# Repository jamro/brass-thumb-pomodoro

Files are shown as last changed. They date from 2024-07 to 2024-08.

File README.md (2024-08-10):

# Brass Thumb Pomodoro

The Brass Thumb Pomodoro is a unique productivity timer inspired by the [Pomodoro Technique](https://en.wikipedia.org/wiki/Pomodoro_Technique) and designed in a delightful steampunk style. This timer, powered by the [Arduino](https://www.arduino.cc/) platform, helps you manage work and rest periods effectively. With 25-minute work intervals followed by 5-minute breaks, the device features a side switch to set the mode. Upon completing a work session, a thumbs-up figure pops out as a reward. The entire gadget is USB-powered and designed with 3D-printed parts, making it portable and convenient to use.

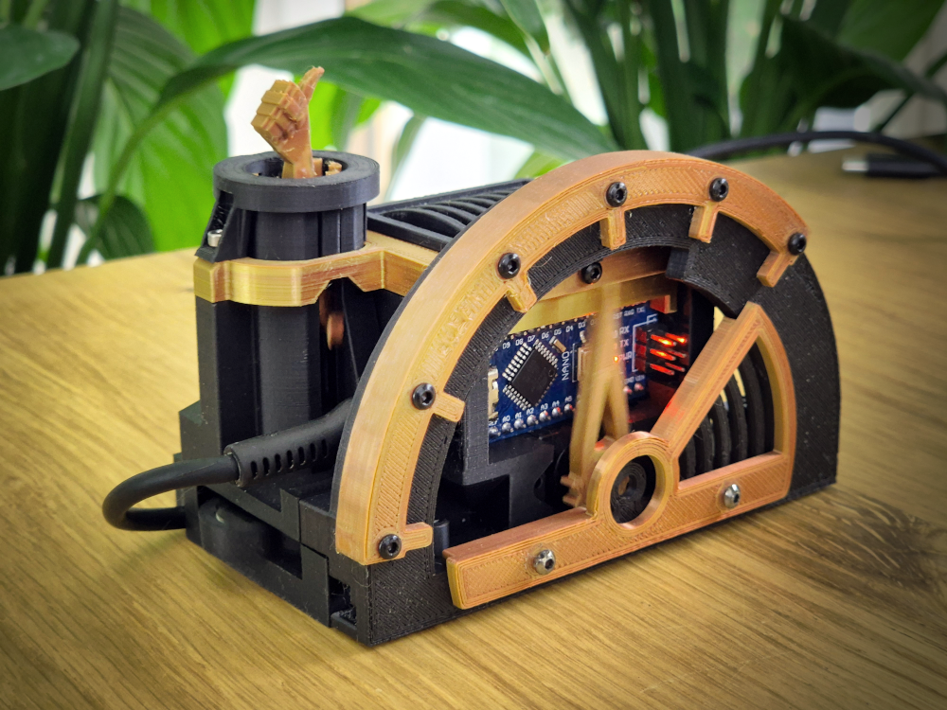
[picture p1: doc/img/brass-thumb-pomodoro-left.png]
Brass Thumb Pomodoro Left View

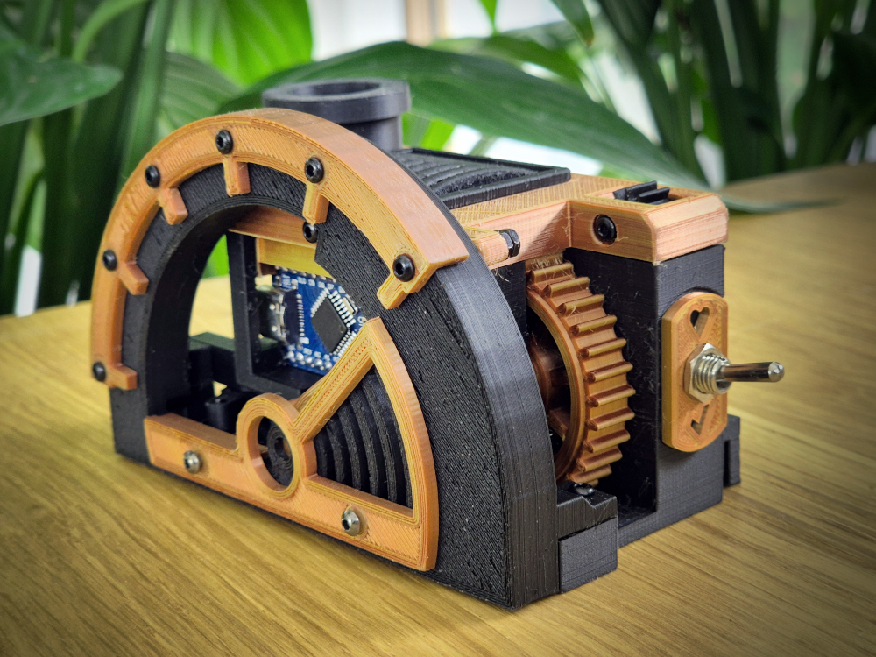
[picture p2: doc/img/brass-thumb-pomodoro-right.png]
Brass Thumb Pomodoro Right View

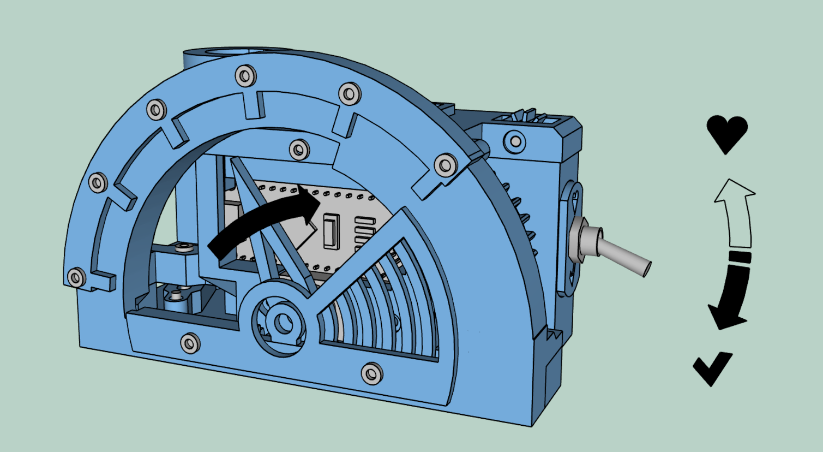
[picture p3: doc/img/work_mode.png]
Work mode


## Documentation

1. **[Materials List](doc/materials_list.md)**
2. **[3D Printing](doc/3d_printing.md)**
3. **[Upload Code](doc/upload_code.md)**
4. **[Wiring Electronics](doc/wiring_electronics.md)**
5. **[Device Assembly](doc/device_assembly.md)**
6. **[User Manual](doc/user_manual.md)**

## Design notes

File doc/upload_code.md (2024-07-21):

# Upload Code

Follow these detailed instructions to build and upload the Brass Thumb Pomodoro project to your Arduino Nano.

## Step 1: Locate the Arduino Sketch Folder

The Arduino IDE stores sketches (projects) in a predefined location known as the "Sketchbook" folder. To find out where this folder is located on your system:

1. Open the Arduino IDE.
2. Go to `File` -> `Preferences`.
3. In the `Preferences` window, locate the `Sketchbook location:` field. This shows the directory where your sketches are stored.

## Step 2: Create the Project Directory

1. Navigate to the Sketchbook location using your file explorer or terminal.
2. Inside the Sketchbook folder, create a new subfolder named `brass-thumb-pomodoro`.

## Step 3: Move Source Files

1. Copy all contents from the `/src` folder of the Brass Thumb Pomodoro project (e.g., `brass-thumb-pomodoro.ino`, `config.h`, `lib/Clock.h`, `lib/Clock.cpp`, and any other necessary files).
2. Paste these files into the `brass-thumb-pomodoro` folder you just created in your Sketchbook directory.

Your folder structure should look like this:
```
Arduino/Sketchbook/
    └── brass-thumb-pomodoro/
        ├── brass-thumb-pomodoro.ino
        ├── config.h
        └── lib/
            ├── Clock.h
            ├── Clock.cpp
            └── ... (other library files)
```

## Step 4: Open the Project in Arduino IDE

1. In the Arduino IDE, go to `File` -> `Sketchbook`.
2. You should see a list of folders within your Sketchbook directory. Click on `brass-thumb-pomodoro`.

This will open the `brass-thumb-pomodoro.ino` file in the Arduino IDE.

## Step 5: Select Arduino Nano

1. Connect your Arduino Nano to your computer via USB.
2. In the Arduino IDE, go to `Tools` -> `Board` and select `Arduino Nano`.
3. Still under `Tools`, select the appropriate processor. Usually, this is `ATmega328P (Old Bootloader)` or `ATmega328P`, depending on your specific Nano version.
4. Under `Tools` -> `Port`, select the port to which the Arduino Nano is connected (e.g., `COM3` on Windows or `/dev/ttyUSB0` on Linux).

## Step 6: Build and Upload

1. To ensure that all components are compiled correctly, click the checkmark (✓) button in the upper-left corner of the Arduino IDE. This runs a verify/compile check.
   - If there are any errors, review the messages in the console for guidance on fixing them.
2. Once the code compiles without errors, click the right-arrow (→) button (Upload) to upload the code to the Arduino Nano.

## Troubleshooting

- **Compilation Errors**: Ensure that all necessary files are within the `brass-thumb-pomodoro` folder. Missing files can cause compilation issues.
- **Port Issues**: Verify that the correct port is selected under `Tools` -> `Port`. You may need to disconnect and reconnect the USB cable or restart the Arduino IDE to resolve port detection issues.
- **Board Not Detected**: Make sure drivers for the Arduino Nano are correctly installed. Some unofficial Nanos require the installation of additional CH340 drivers.
- **Mode Switch Orientation**: If the mode switch is installed upside down, the positions of the WORK and BREAK modes will be inverted. To fix this:
    1. Open the `config.h` file in the `brass-thumb-pomodoro` folder.
    2. Swap the following values:
        ```cpp
        constexpr int WORK_PIN = 2; // was 3
        constexpr int BREAK_PIN = 3; // was 2
        ```
    3. Save the file and re-upload the code to the Arduino Nano.

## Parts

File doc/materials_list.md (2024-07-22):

# List of Materials

## Electronics
- [Arduino Nano (clone with USB-C)](https://sklep.msalamon.pl/produkt/nano-v3-0-z-usb-c-zgodny-z-arduino)
- [3 Position Switch](https://sklep.msalamon.pl/produkt/przelacznik-dzwigniowy-pojedynczy-spdt-3p/)
- Servo Redox S90
- Female Jumper Wires

## Screws
- 11 x M2x8 Screws
- 5 x M2x16 Screws

## Filaments
- [PLA Matte Black (65g)](https://eryone3d.com/products/matte-pla)
- [PLA Copper (25g)](https://sklep.rosa3d.pl/product/pla-silk-175mm-copper-08kg/)

## Tools
- 3D Printer
- Soldering Iron
- Tin
- Mini Screwdriver

## Preparation
Ensure you collect all necessary parts before starting the assembly.

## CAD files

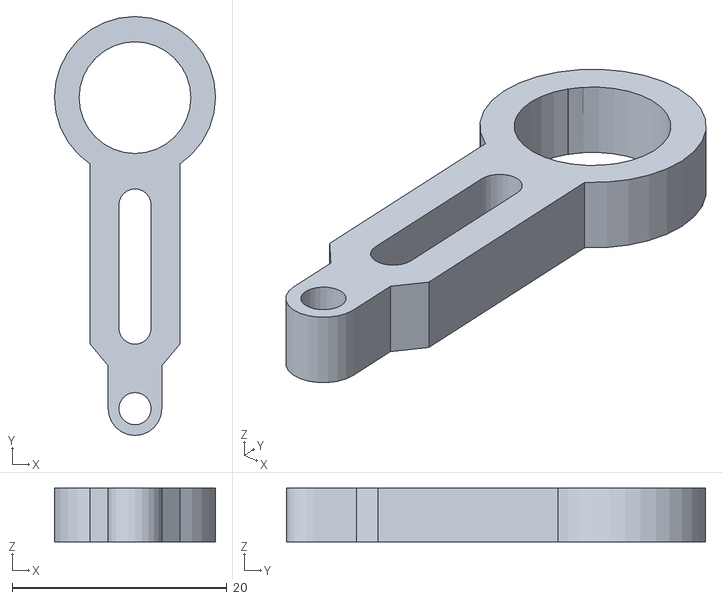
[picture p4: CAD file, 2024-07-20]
model/stl/gauge_handle.stl
15.0 x 39.0 x 5.00

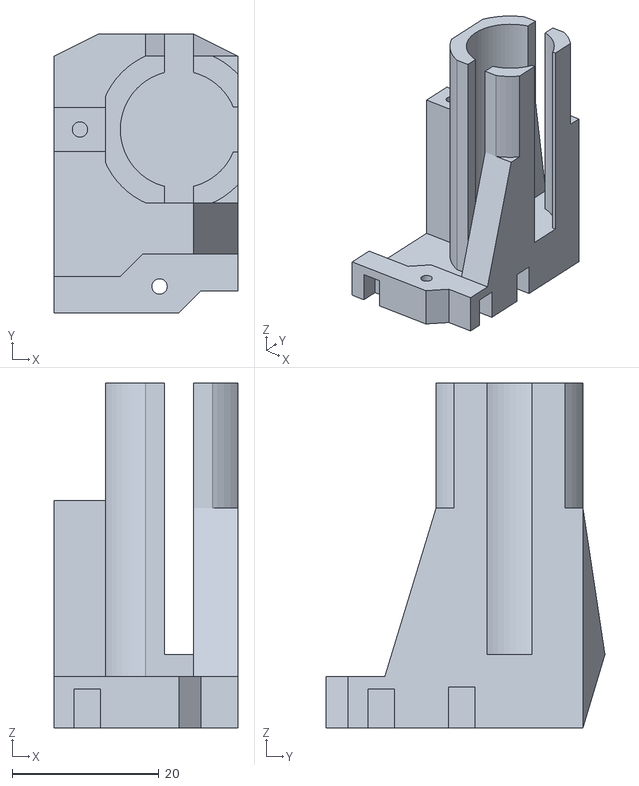
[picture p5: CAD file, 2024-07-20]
model/stl/gauge_tower.stl
25.0 x 38.0 x 47.0

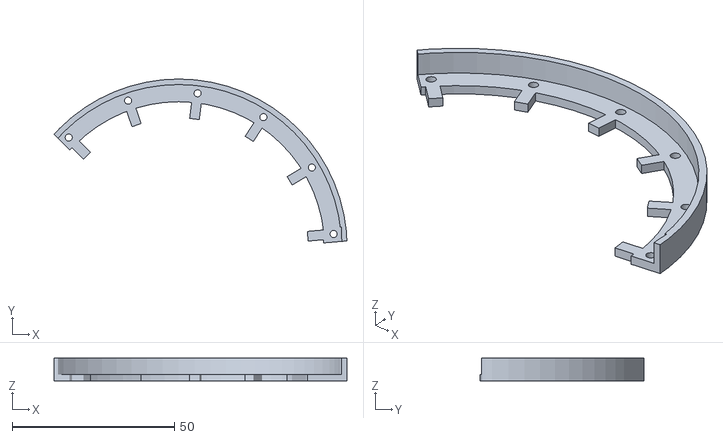
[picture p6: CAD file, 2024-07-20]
model/stl/gauge_scale_ticks.stl
90.4 x 50.6 x 7.00

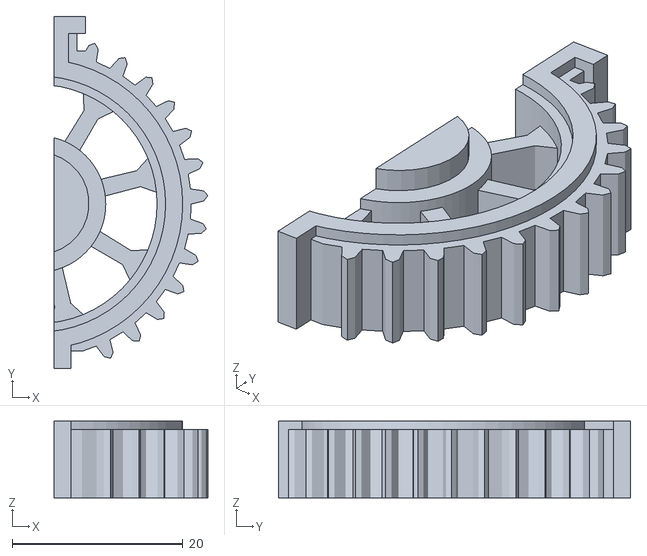
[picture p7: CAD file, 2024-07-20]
model/stl/gauge_gear_large.stl
18.0 x 41.2 x 9.00

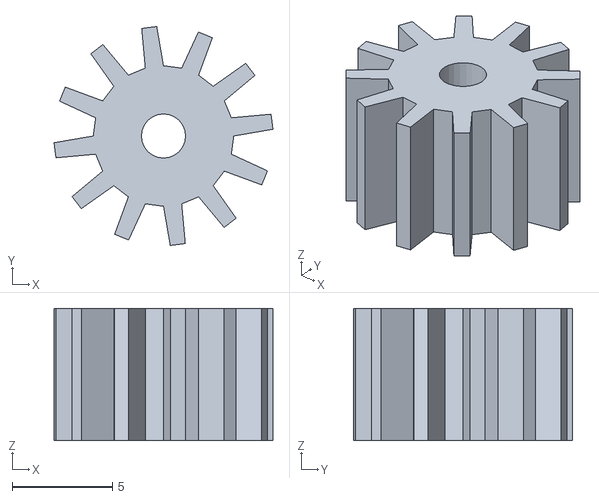
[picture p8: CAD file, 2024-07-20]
model/stl/gauge_gear_small.stl
10.9 x 10.9 x 6.60

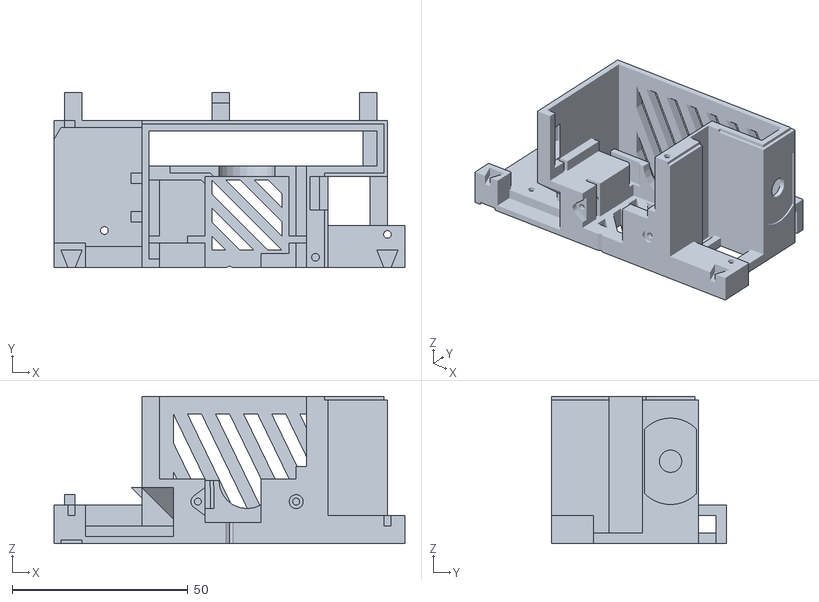
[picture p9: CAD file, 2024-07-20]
model/stl/gauge_case.stl
100.0 x 50.0 x 42.0

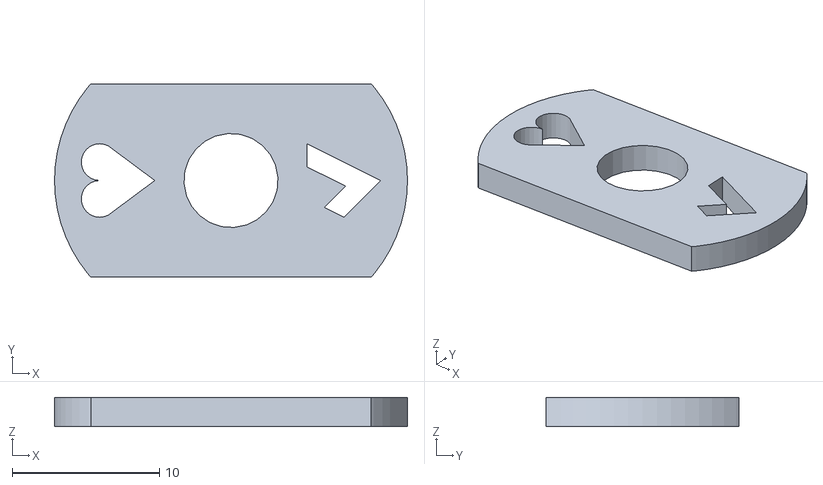
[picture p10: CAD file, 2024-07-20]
model/stl/gauge_tag.stl
24.0 x 13.1 x 2.00

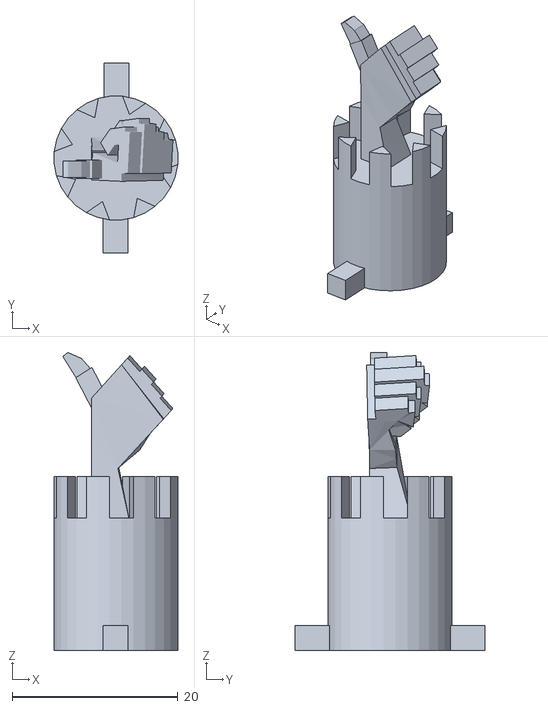
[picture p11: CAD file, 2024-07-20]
model/stl/gauge_popup.stl
14.9 x 22.9 x 36.0

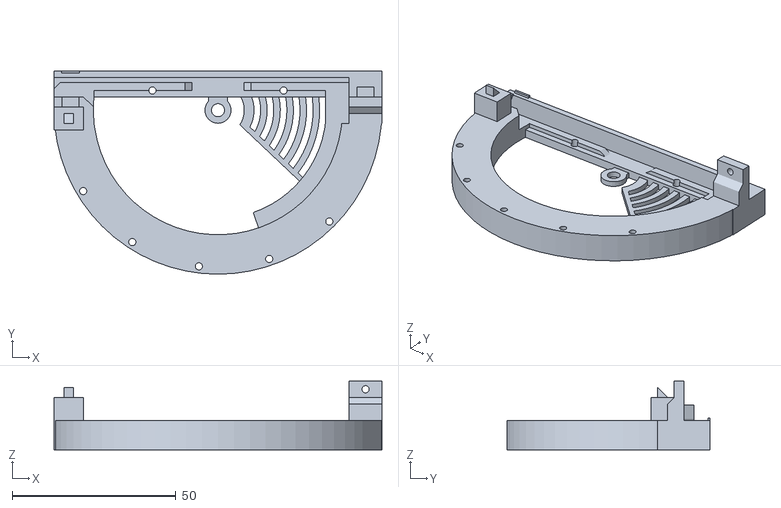
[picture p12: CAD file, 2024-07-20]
model/stl/gauge_scale_body.stl
100.0 x 62.0 x 21.0

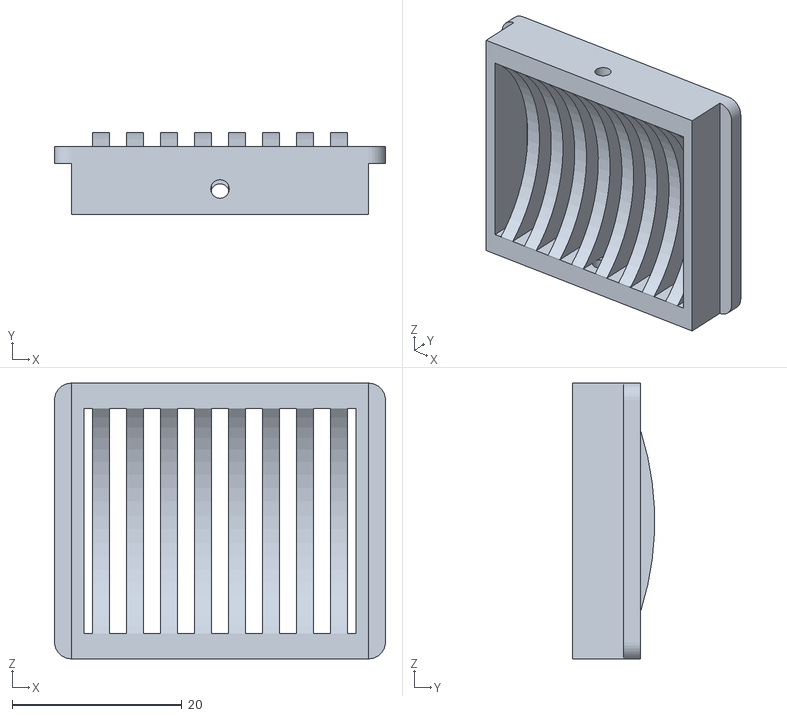
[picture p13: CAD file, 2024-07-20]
model/stl/gauge_vent.stl
39.0 x 9.65 x 32.5

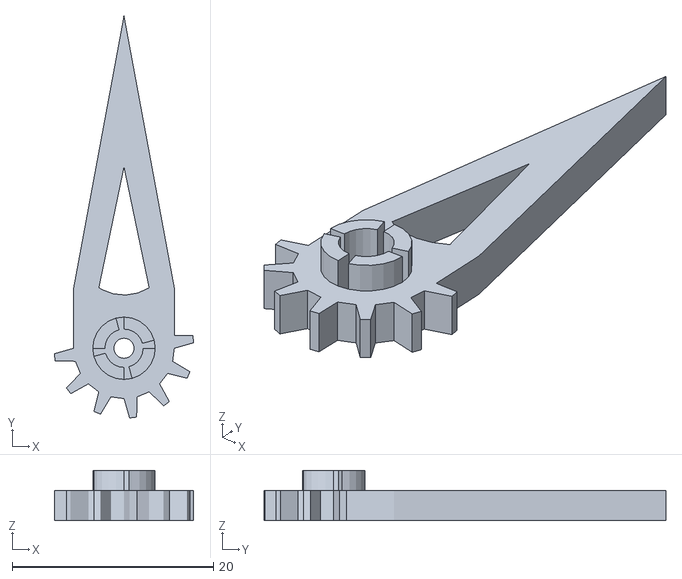
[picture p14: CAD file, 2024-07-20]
model/stl/gauge_pointer.stl
13.9 x 39.9 x 5.00

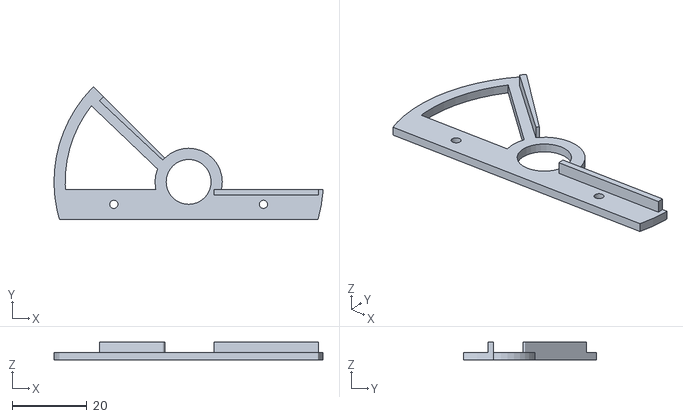
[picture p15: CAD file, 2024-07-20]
model/stl/gauge_scale_front.stl
71.9 x 35.4 x 4.70

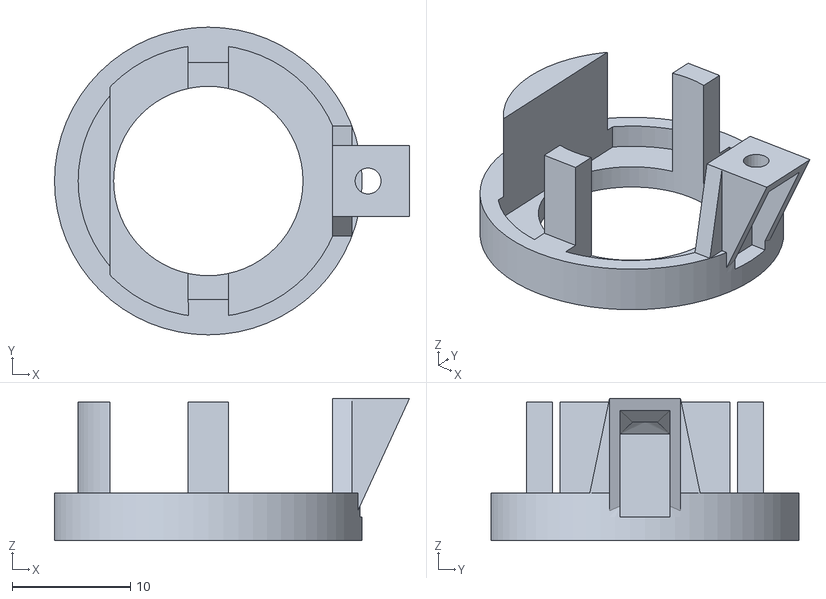
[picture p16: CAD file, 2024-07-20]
model/stl/gauge_tower_top.stl
30.0 x 26.0 x 12.0

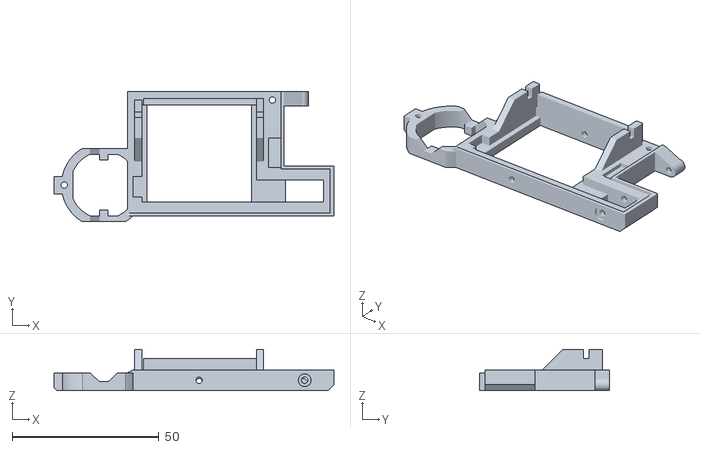
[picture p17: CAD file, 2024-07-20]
model/stl/gauge_cap.stl
95.5 x 44.5 x 14.0

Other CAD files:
model/stl/gauge_slider.stl
model/skp/gauge_cap.skp
model/skp/gauge_case.skp
model/skp/gauge_gear_large.skp
model/skp/gauge_gear_small.skp
model/skp/gauge_handle.skp
model/skp/gauge_pointer.skp
model/skp/gauge_popup.skp
model/skp/gauge_scale_body.skp
model/skp/gauge_scale_front.skp
model/skp/gauge_scale_ticks.skp
model/skp/gauge_slider.skp
model/skp/gauge_tag.skp
model/skp/gauge_tower.skp
model/skp/gauge_tower_top.skp
model/skp/gauge_vent.skp

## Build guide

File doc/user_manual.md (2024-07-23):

# User Manual

## Getting Started

1. **Power the Device**: Connect using a USB cable.
2. **Set the Timer**:
   - **Down Position (Work Mode)**: 25-minute work interval.
   - **Up Position (Rest Mode)**: 5-minute break interval.
   - **Middle Position (Pause Mode)**: Pause the timer.

## Operating Instructions

### Initial Testing Sequence
1. **Power On**:
   - After powering on, the device's pointer will move back and forth to test if the thumbs-up mechanism works properly.
   - Ensure the thumbs-up figure pops out and retracts smoothly during this test.

### Work Mode

1. Slide the switch up for a 25-minute work period.
2. The timer counts down from 25 minutes.
3. The thumbs-up figure pops up when the work period is complete.
4. Switch to **Rest mode** when ready.

Work mode

### Rest Mode

1. Slide the switch down for a 5-minute rest period.
2. The timer counts down from 5 minutes, during which the pointer will move backward to indicate rest. 
3. Switch back to **Work mode** as needed.

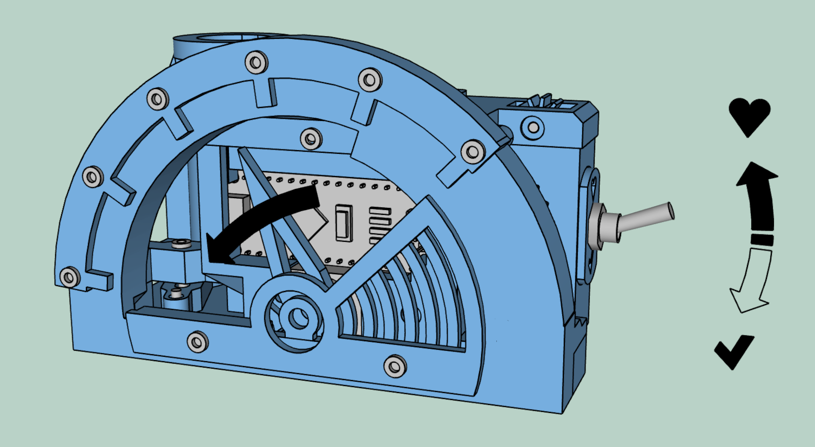
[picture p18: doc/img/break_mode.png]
Rest mode


### Pause Mode

1. Slide the switch to the middle to pause the timer in either work or rest mode.
2. Slide the switch back to resume the timer from where it paused.

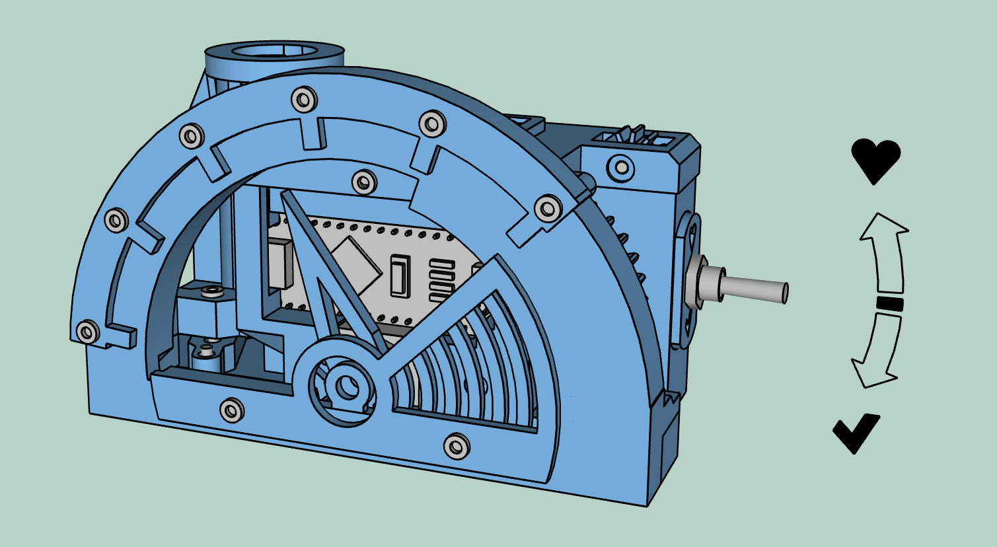
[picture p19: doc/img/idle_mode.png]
Pause mode


## Maintenance

- **Cleaning**:
  - Use a soft, damp cloth to clean the exterior.
  - Avoid using water or any liquid directly on electronic parts.
  - Do not use harsh chemicals or abrasives.

- **Storage**:
  - Store the timer in a dry place when not in use.
  - Avoid exposing the device to extreme temperatures or humidity.
  - Keep the device away from dust and direct sunlight.

## Troubleshooting

- **Not Powering On**:
  - Ensure the USB connection is secure.
  - Try a different USB power source or cable.
  - Check for any visible damage to the USB port.

- **Timer Not Starting/Malfunctioning**:
  - Verify the switch position; ensure it's fully engaged in the desired mode.
  - Reset the device by unplugging and replugging it.

- **Thumbs-Up Figure Issues**:
  - Ensure the device is on a stable and level surface.
  - Manually check if the thumbs-up figure is obstructed or stuck.
  - If persistent, disconnect and reconnect the USB power to reset the system.

Enjoy your productivity with The Brass Thumb Pomodoro!

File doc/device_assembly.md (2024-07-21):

# Brass Thumb Pomodoro Assembly Guide

Welcome to the assembly guide for the Brass Thumb Pomodoro, your steampunk productivity timer. This guide is divided into two parts: 

1. **Preparation**: Assemble smaller components.
2. **Main Assembly**: Combine parts into the final device.

**Prerequisites**: Complete each step sequentially for a smooth assembly.

**Tools needed**: Mini screwdriver, USB power source.

Let's get started!

## Preparation

Before we dive into the main assembly of the Brass Thumb Pomodoro, we'll start by preparing a few smaller components. This step is essential as it will make the final assembly smoother and more efficient. Let's prepare each part carefully.

### Device Top Cover

**Mount Gauge Vent**: Place the `gauge_vent.stl` into the `gauge_cap.stl` as shown. Secure it with two M2x8 screws. 

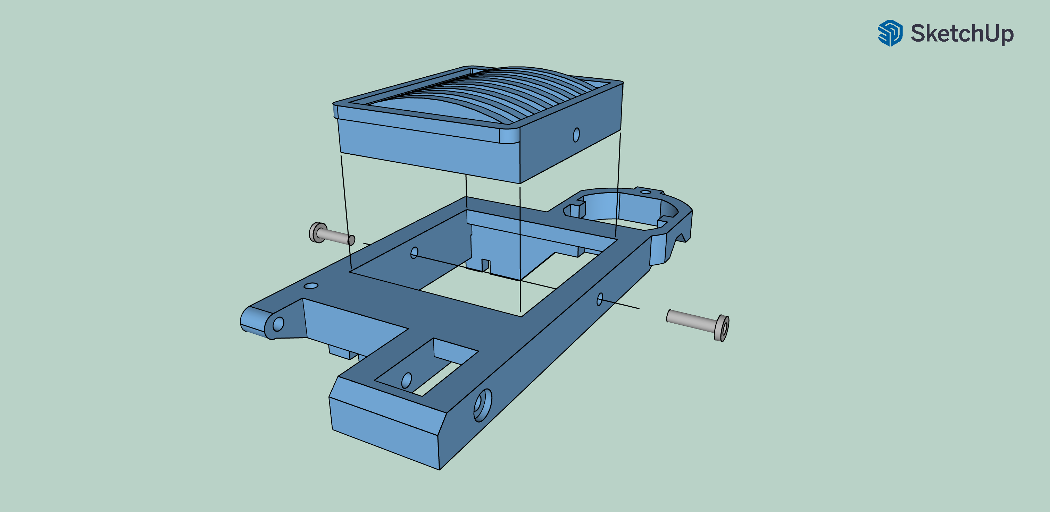
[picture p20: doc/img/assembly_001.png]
Mount Gauge Vent


**Mount Gauge Gear**: Insert the `gauge_gear_small.stl` into the designated slot in `gauge_cap.stl`. Use one M2x16 screw to secure it in place.

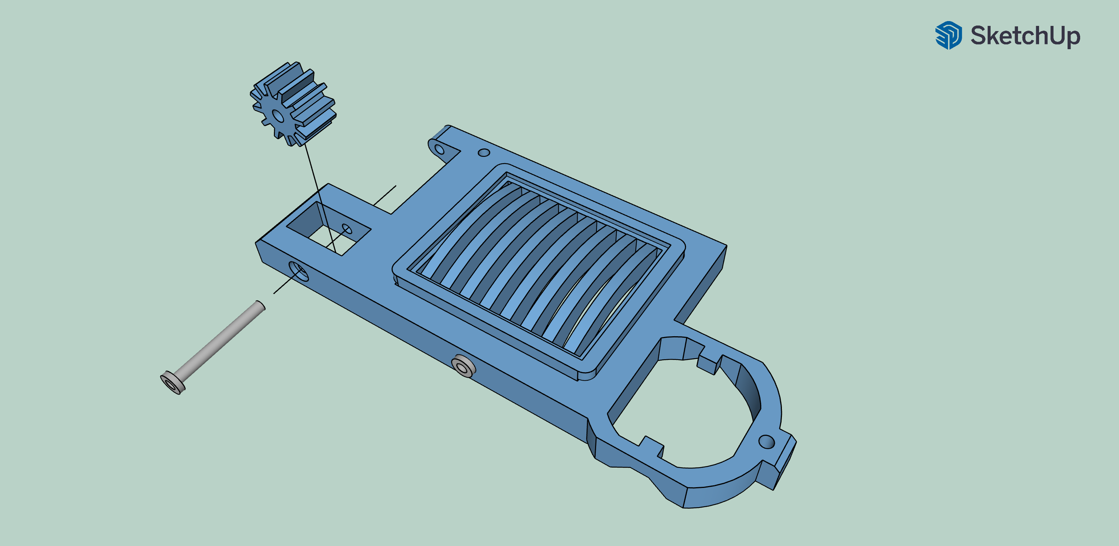
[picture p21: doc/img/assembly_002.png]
Mount Gauge Gear


### Thumb Up Popup

Prepare the popup mechanism for the Brass Thumb Pomodoro by following these steps:

Insert the 10mm diameter, 5mm height cylinder magnet into the bay of the `gauge_popup.stl` as shown in the image. The magnet's orientation is not important at this stage.

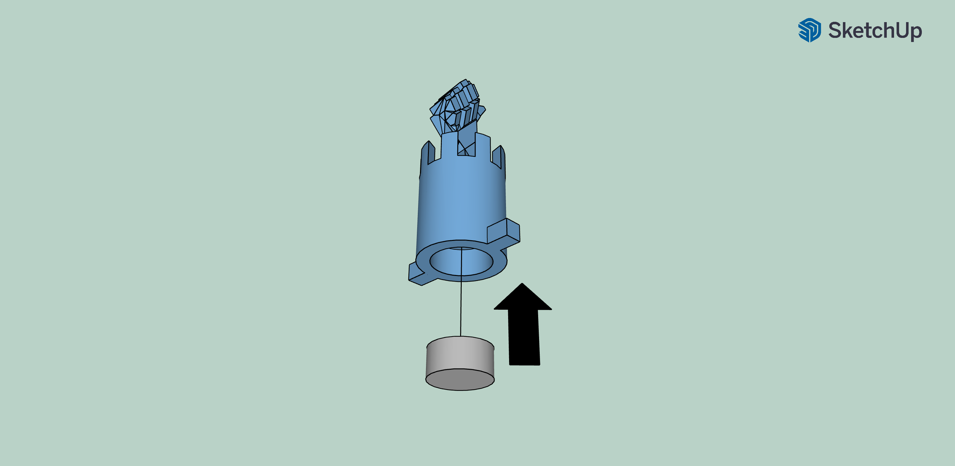
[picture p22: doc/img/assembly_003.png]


Ensure the magnet fits snugly in the bay. If it’s loose, secure it using adhesive tape on the sides.

### Magnetic Handle
Use the cylinder magnet (D=10mm, h=5mm) as shown below. The orientation of the magnet does not matter at this stage. Place the magnet securely in the bay of `gauge_handle.stl`. If it is loose, use adhesive tape on the sides to tighten it.

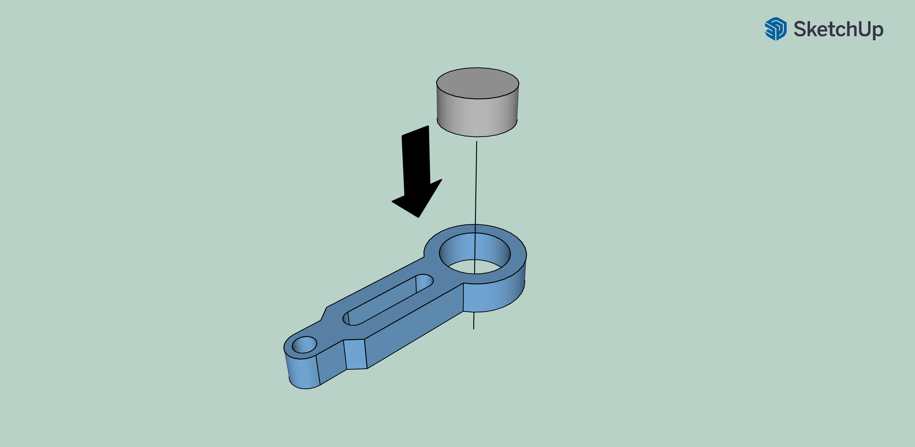
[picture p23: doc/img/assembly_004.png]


### Rack Gear

Insert the M2x8 screw through the hole from the bottom side of the rack gear (`gauge_slider.stl`) and tighten it until firmly held in place. This will be used later to mount other elements.

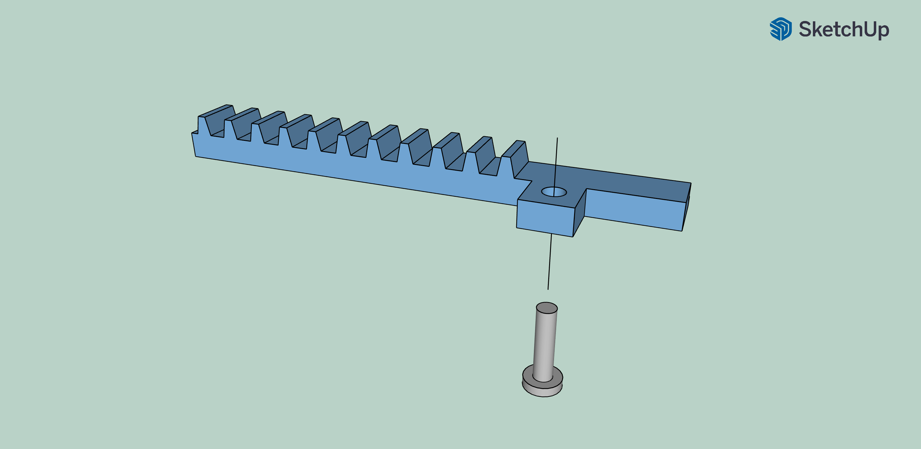
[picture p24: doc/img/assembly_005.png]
Rack Gear Assembly


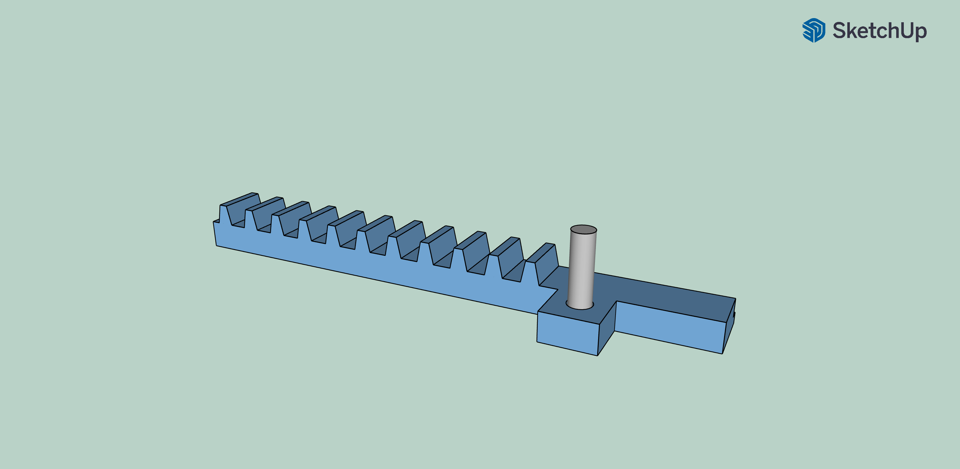
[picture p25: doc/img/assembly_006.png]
Rack Gear Assembly


## Main Assembly of the Device

With all the smaller components prepared, it's time to bring everything together to complete your Brass Thumb Pomodoro. The following steps will guide you through assembling the main parts of the device, connecting the Arduino board and servo, and securing everything into the final, functional timer. Follow each step carefully to ensure all components fit together seamlessly, and your device operates smoothly.

### Install Scale

Align the `gauge_scale_body.stl` with the dovetail joints on the `gauge_case.stl` housing. Carefully slide the `gauge_scale_body.stl` into the joints, ensuring it is placed securely and flush with the main housing. 

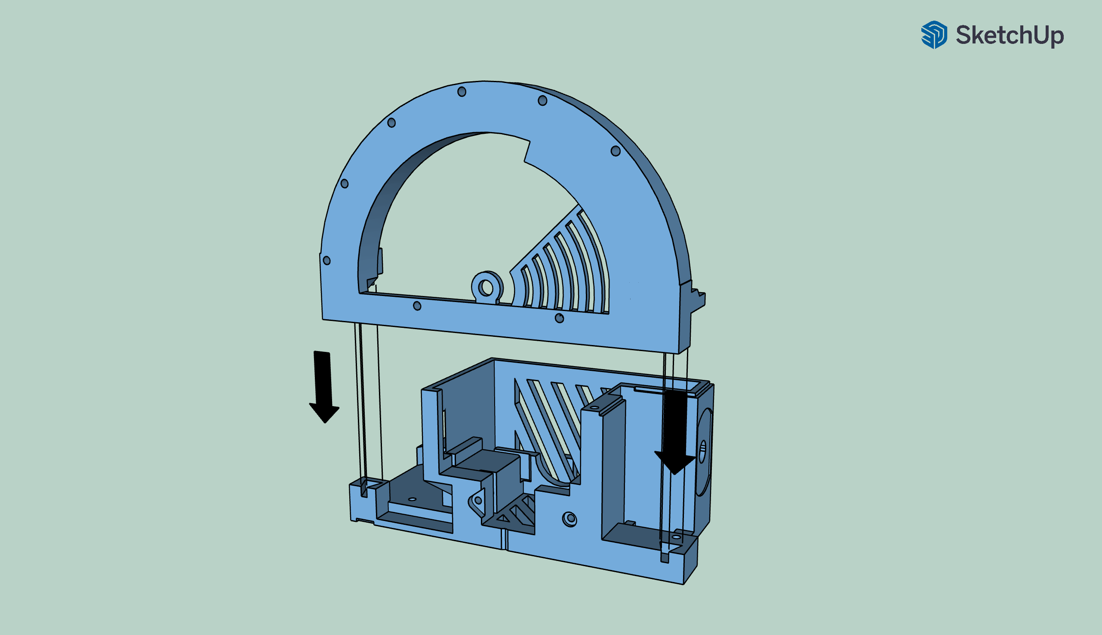
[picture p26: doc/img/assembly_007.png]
Install Scale Parts

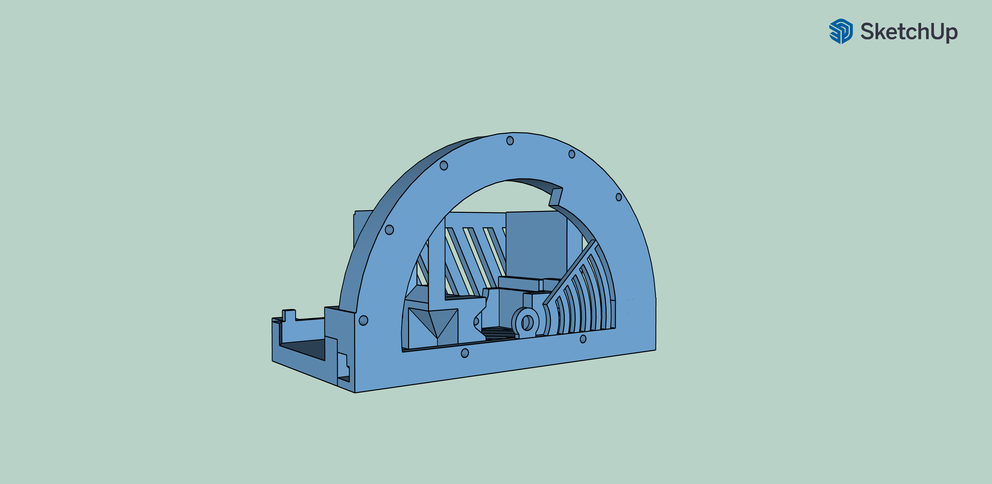
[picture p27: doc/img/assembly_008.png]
Installed Scale


### Add Rack Gear

Insert the previously assembled rack gear (`gauge_slider.stl`) into the guide slot in the main body. Ensure the gear teeth face towards the inner mechanism and the rack gear can move freely sideways.

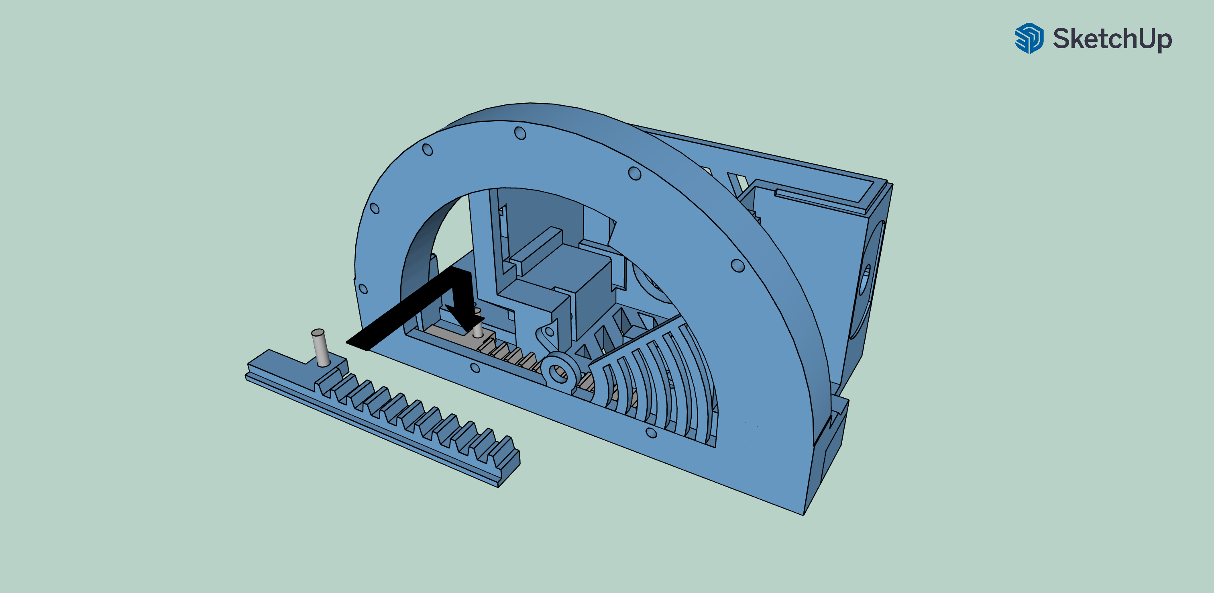
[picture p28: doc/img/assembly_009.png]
Add Rack Gear


### Mount Pointer

Use the screw delivered with the servo to attach the pointer (`gauge_pointer.stl`) to the servo. Insert the screw through the center hole of the pointer and secure it into the servo as shown below.

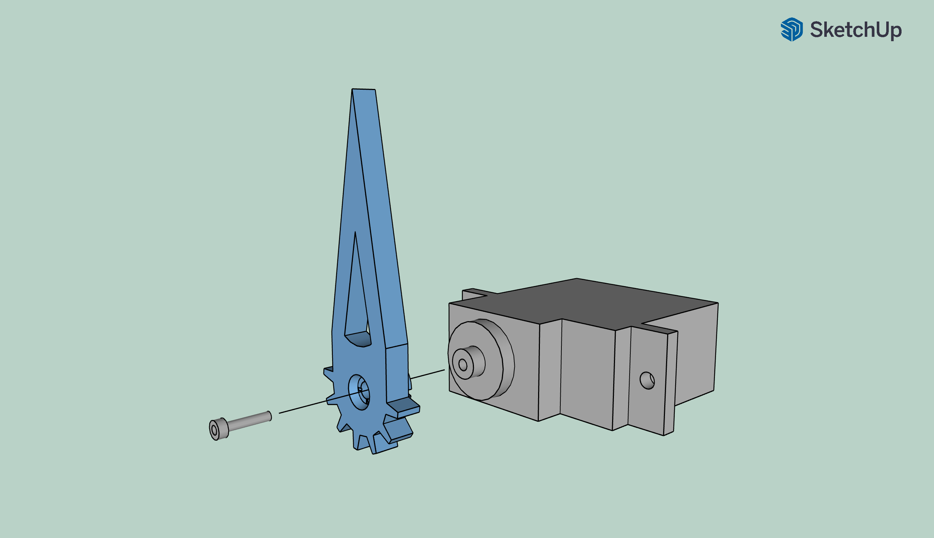
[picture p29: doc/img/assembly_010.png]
Mount Pointer


Proper pointer positioning is crucial. Follow these steps to ensure accuracy:

1. Set the mode switch to the neutral (central) position.
2. Power up the Arduino. This will cause the servo to move back and forth, eventually stopping at the most left position.

In this position, the pointer should be oriented to point left. Ensure the pointer can move smoothly through 90 degrees (pointing up) and up to 180 degrees (pointing right).

Make sure the servo is oriented correctly with the longer part on the right as illustrated below.

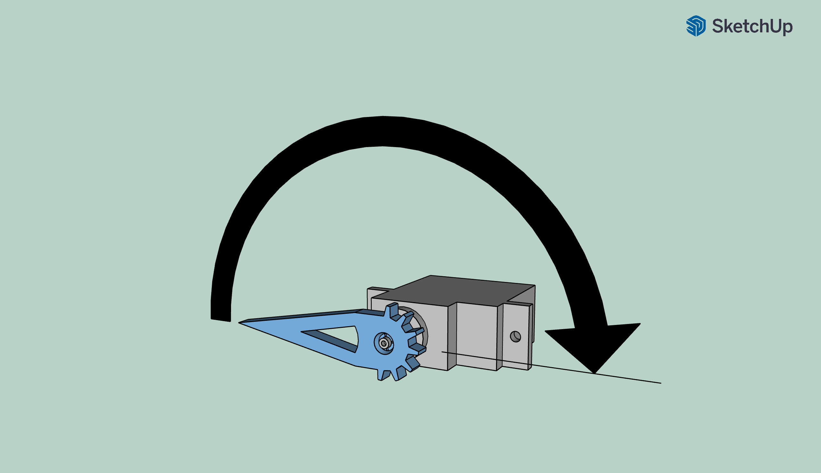
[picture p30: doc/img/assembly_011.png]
Pointer Position


### Mount Servo

Slide the servo into the housing (`gauge_case.stl`) into the dedicated bay as shown in the image.

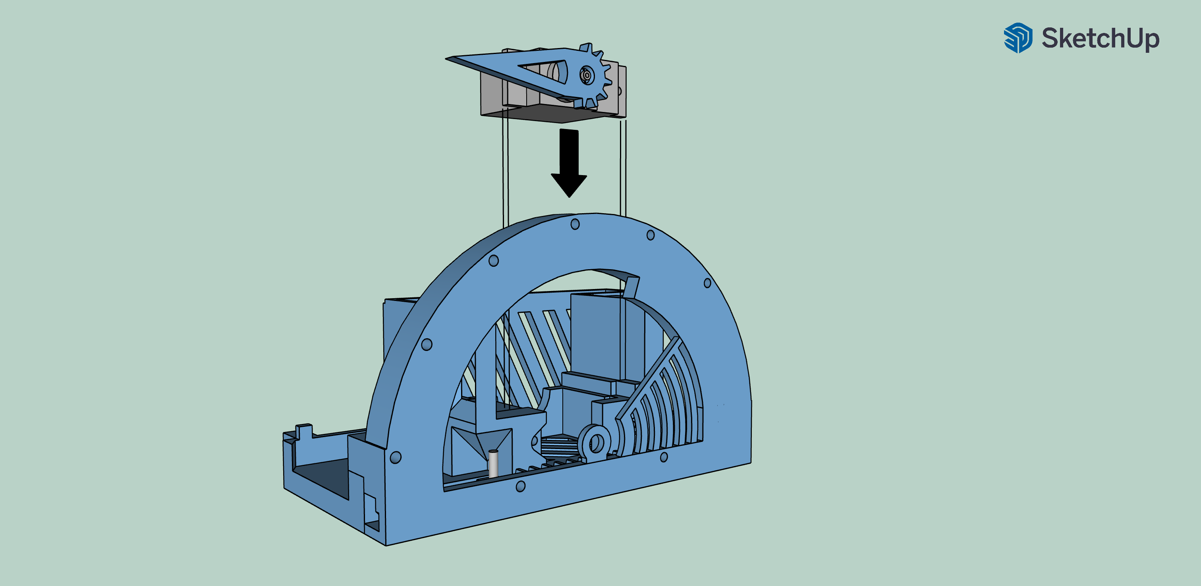
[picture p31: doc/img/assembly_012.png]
Slide Servo into Housing


Make sure the gear on the pointer (`gauge_pointer.stl`) is properly positioned to the rack gear (`gauge_slider.stl`). The gear teeth should fit together perfectly. Ensure that the pointer of the servo is pointing to the left, while the pin mount of the rack gear should be placed to the most right in its slot as displayed in the image below.

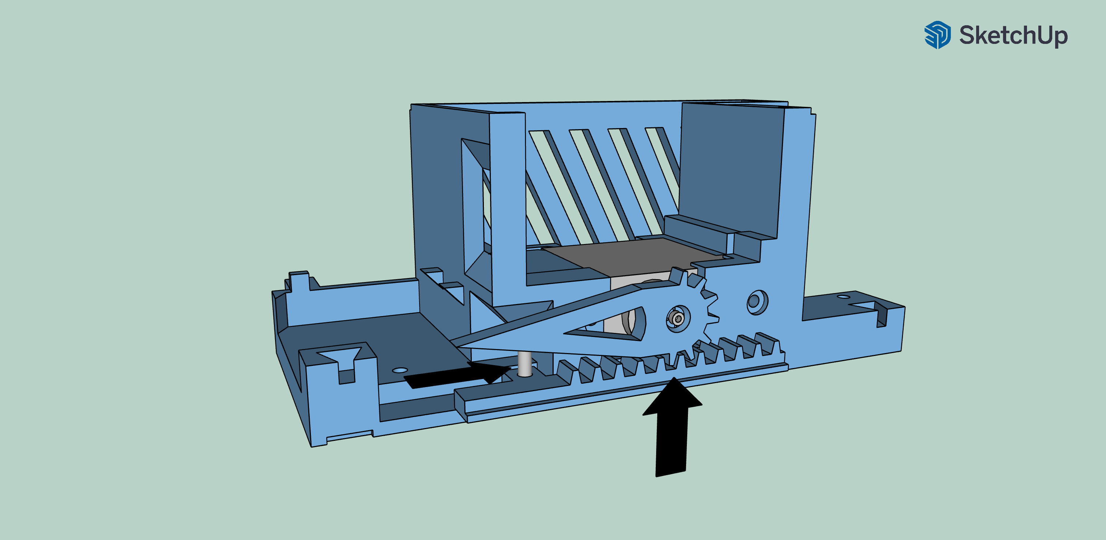
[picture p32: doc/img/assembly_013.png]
Proper Gear Positioning


### Mount Arduino Board

Slide the Arduino board into the housing (`gauge_case.stl`) in the dedicated slot, above the servo.

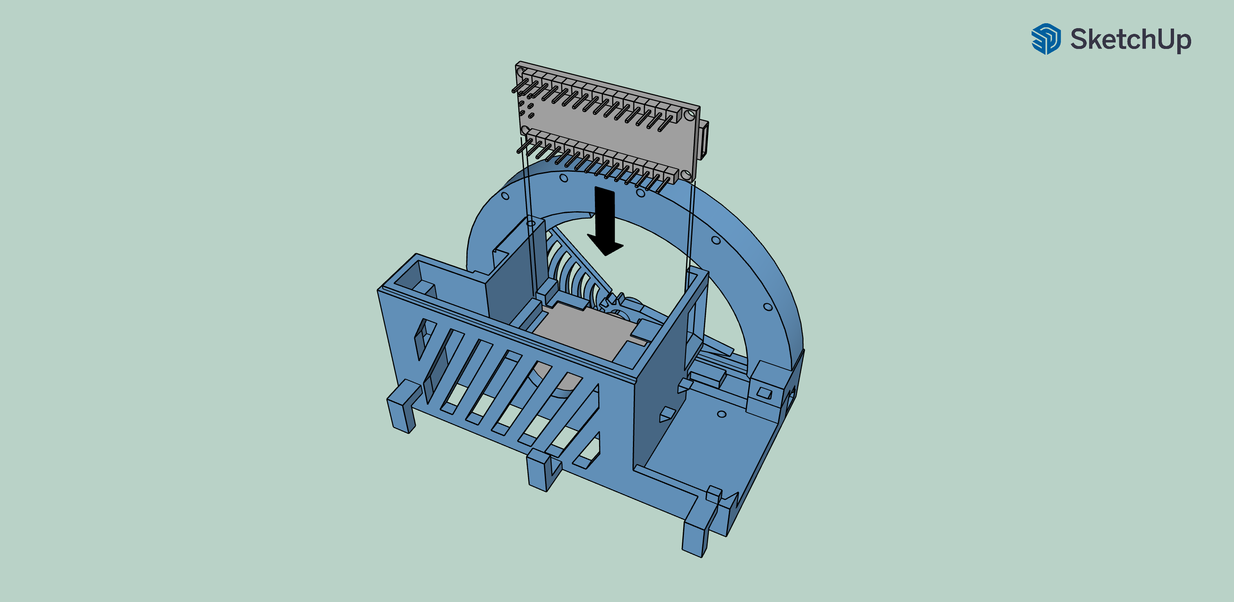
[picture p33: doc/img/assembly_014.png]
Arduino Placement


Make sure the Arduino board is securely and properly installed, with the USB port facing outward for easy access.

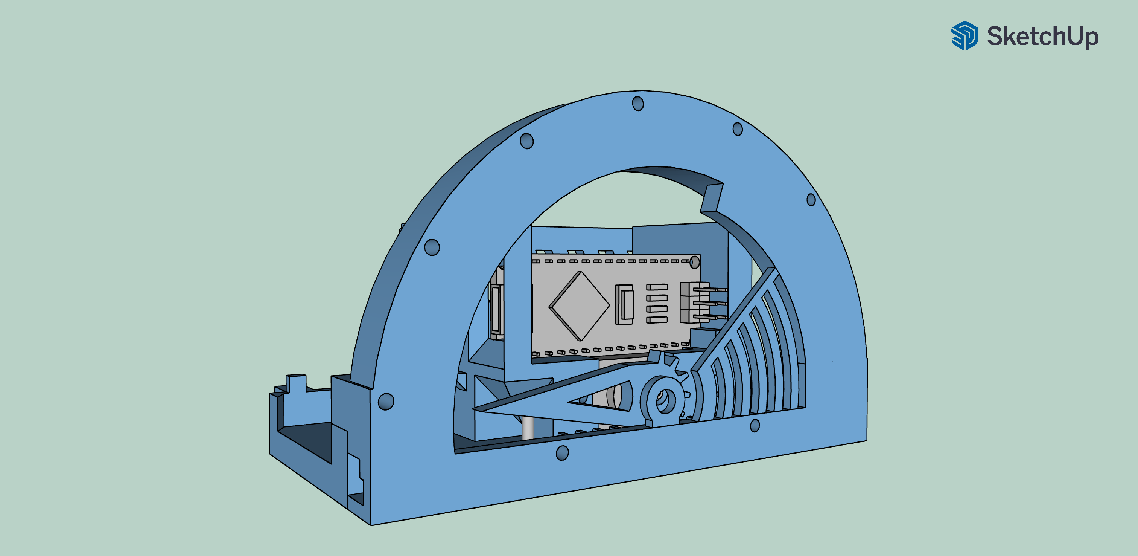
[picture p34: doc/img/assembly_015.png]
Arduino Placement Complete


### Mount Switch

Place the three-position mode switch into the mounting hole of `gauge_case.stl`.

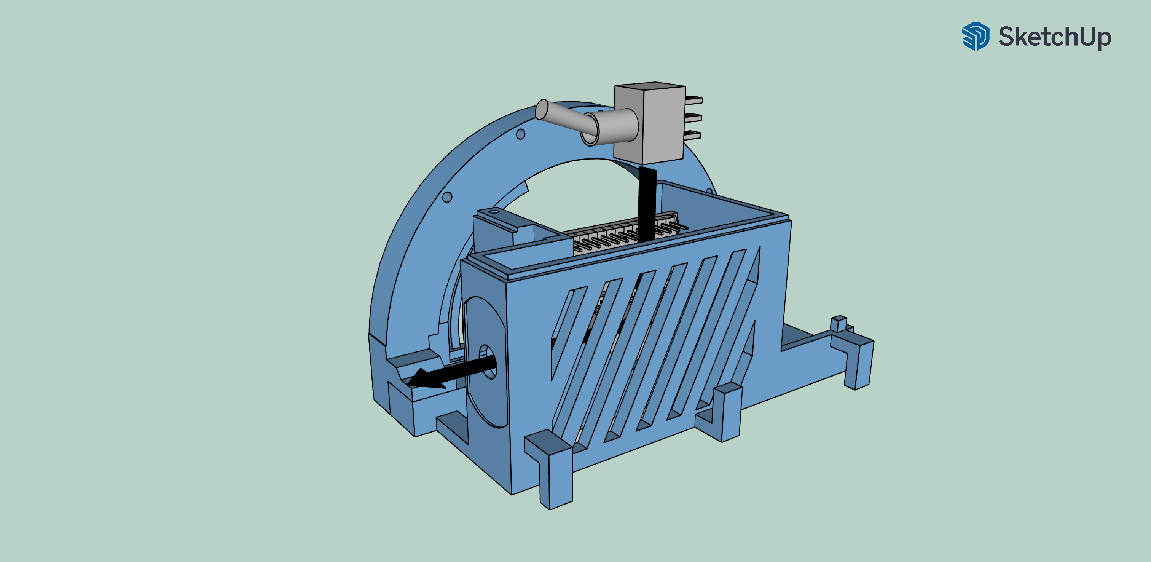
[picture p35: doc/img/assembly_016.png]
Place Switch


Position the mode tag (`gauge_tag.stl`) on the switch with the correct orientation (ensure the heart symbol is at the top). Secure the tag with the screw nut provided.

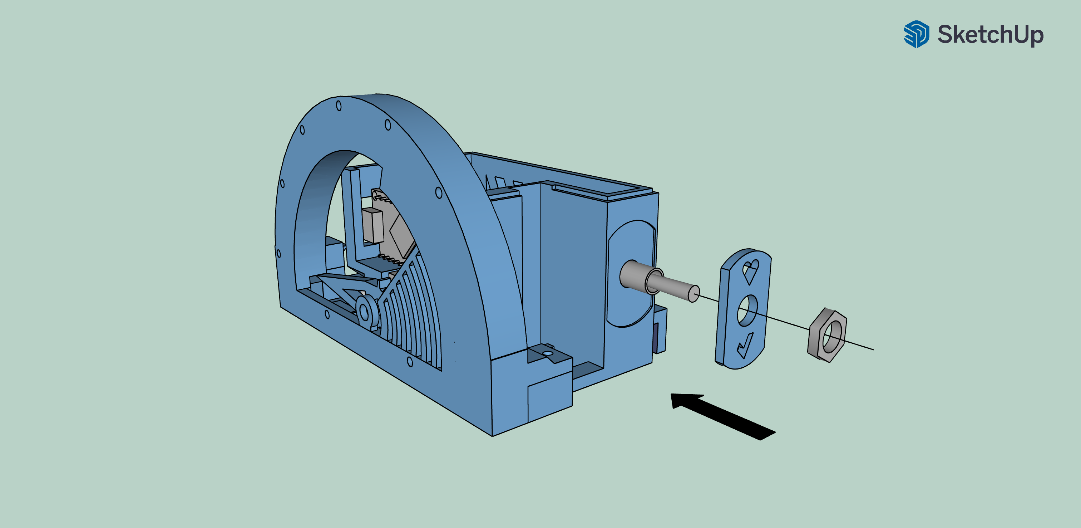
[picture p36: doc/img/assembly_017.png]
Attach Tag


Ensure the switch and tag are firmly in place, as shown below.

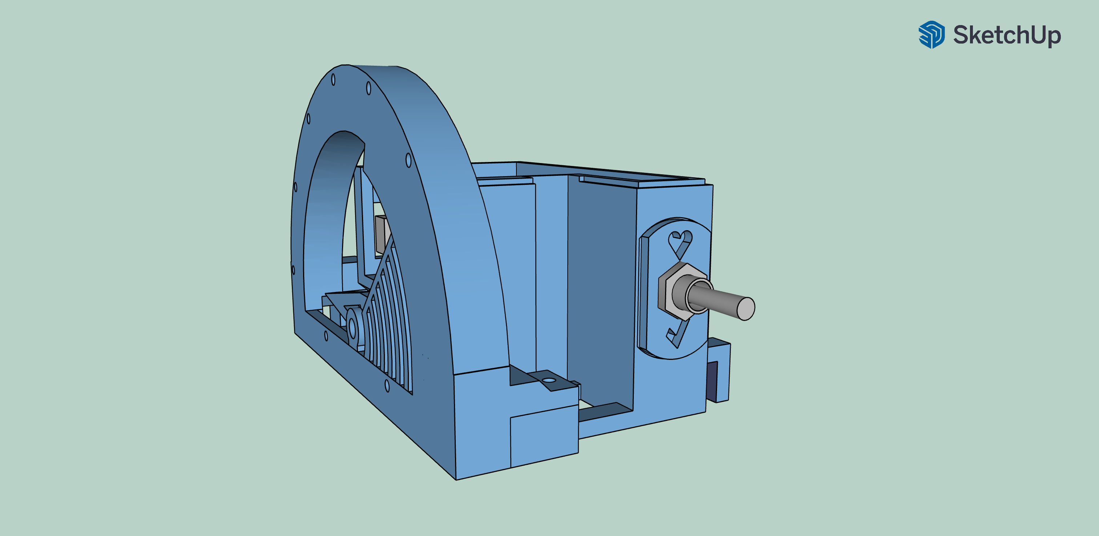
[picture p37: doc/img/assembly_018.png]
Completed Switch Installation


### Install Magnetic Handler

Turn the mode switch to the up position (break mode). This moves the pointer to the right and the rack gear to the left, making the pin on the rack gear more accessible.

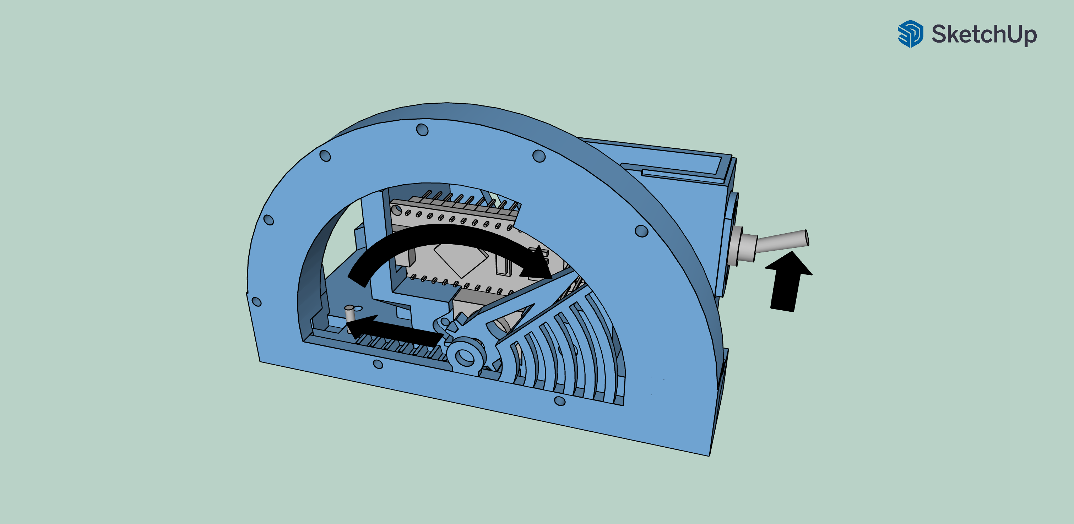
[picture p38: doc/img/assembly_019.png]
Turn Mode Switch


**IMPORTANT**: The 3-position switch is symmetric and can be installed upside down. If this happens, reorient the switch, or switch it to the down position. You can swap its positions in the code later if necessary.

Place the `gauge_handle.stl` mounting hole onto the pin of the rack gear.

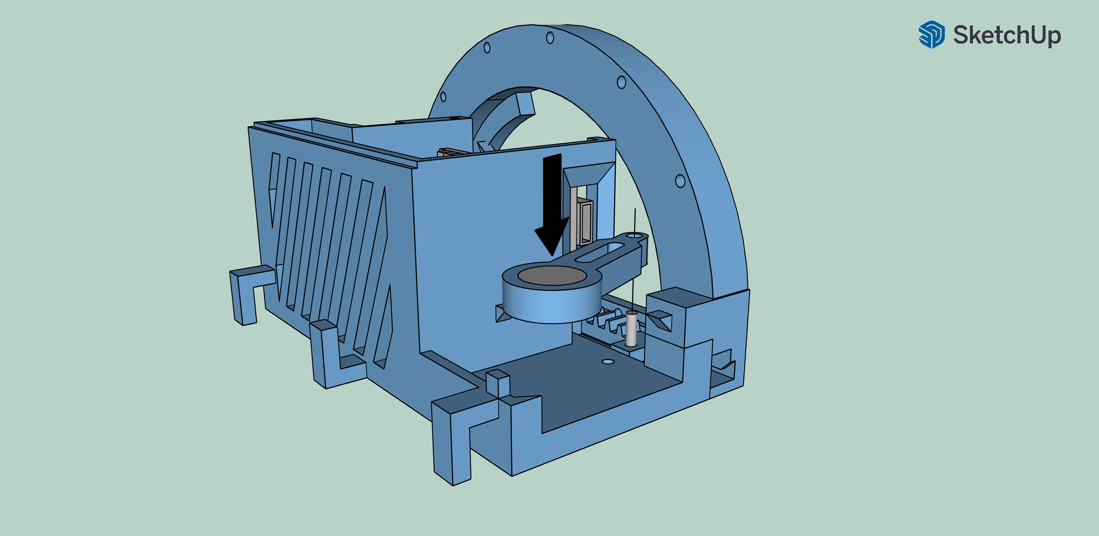
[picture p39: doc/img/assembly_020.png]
Place Gauge Handle


Ensure that the magnets installed in both `gauge_handle.stl` and `gauge_popup.stl` are oriented to push away from each other. If not, reorient the `gauge_handle.stl`.

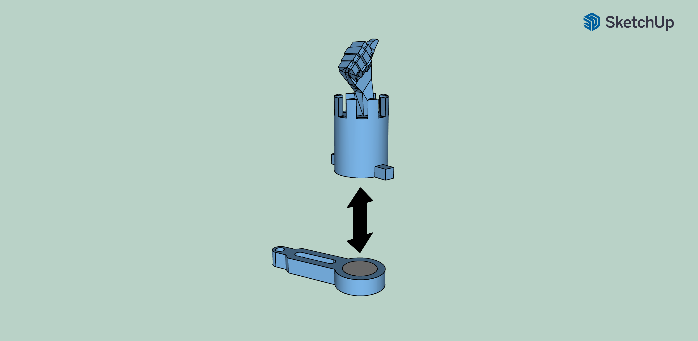
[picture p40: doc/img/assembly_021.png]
Ensure Correct Magnet Orientation


Orient the `gauge_handle.stl` so its guide slot aligns with the hole in the housing (`gauge_case.stl`).

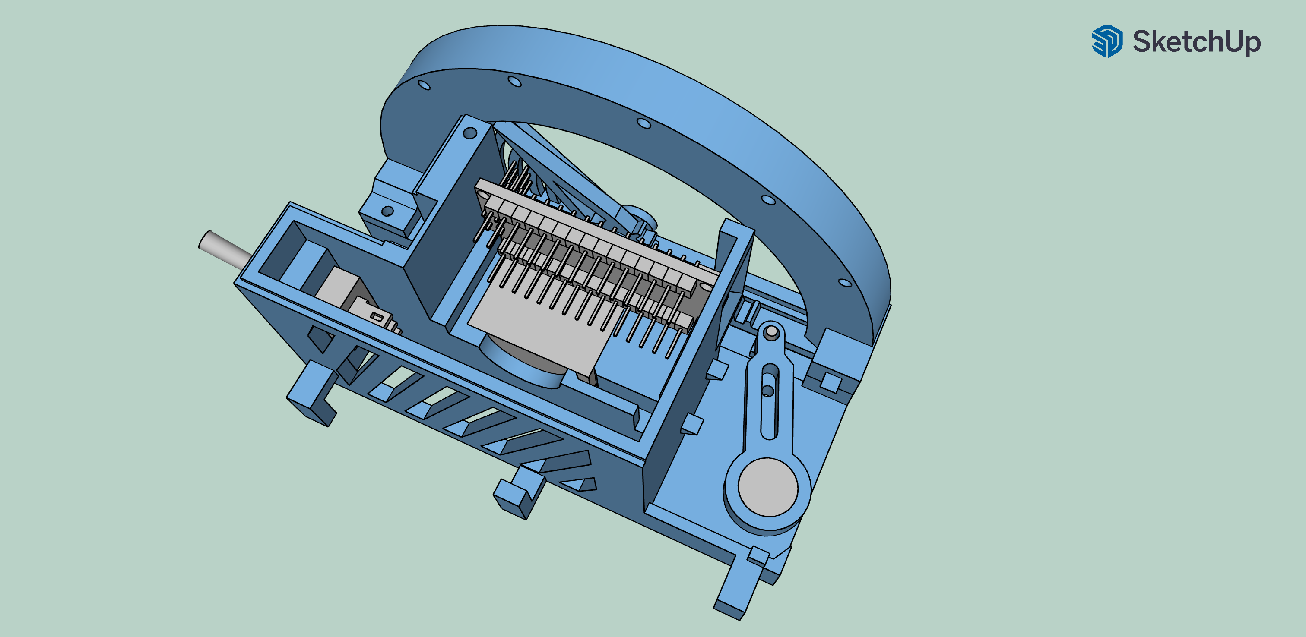
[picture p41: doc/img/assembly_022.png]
Align Gauge Handle


### Install Thumb Up Popup

Slide the `gauge_tower.stl` into the dedicated slots of the `gauge_case.stl`.

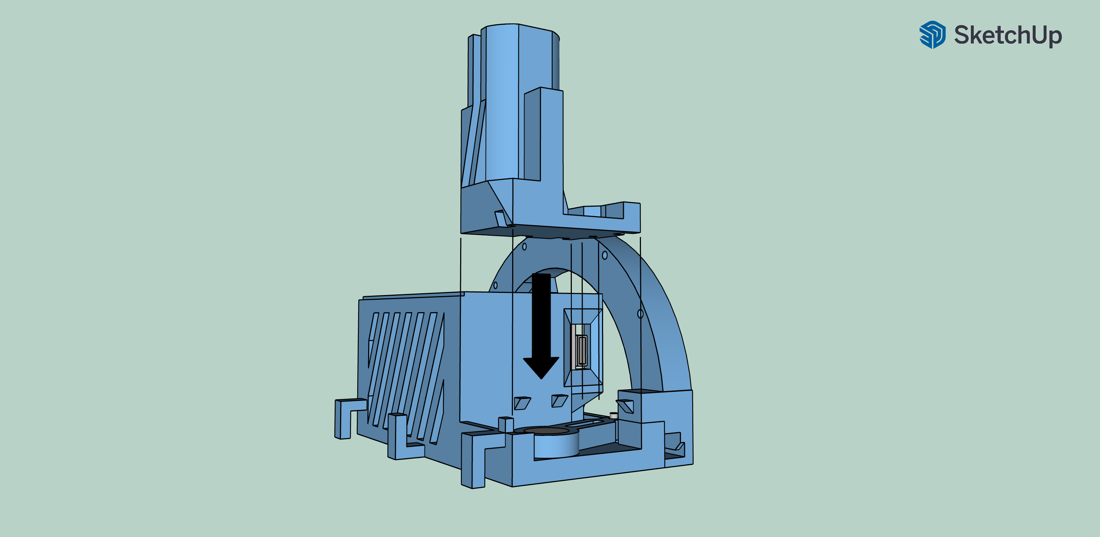
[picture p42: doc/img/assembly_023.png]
Slide Gauge Tower


Secure the `gauge_tower.stl` with an M2x16 screw, ensuring the screw passes through the guide slot of the `gauge_handle.stl`.

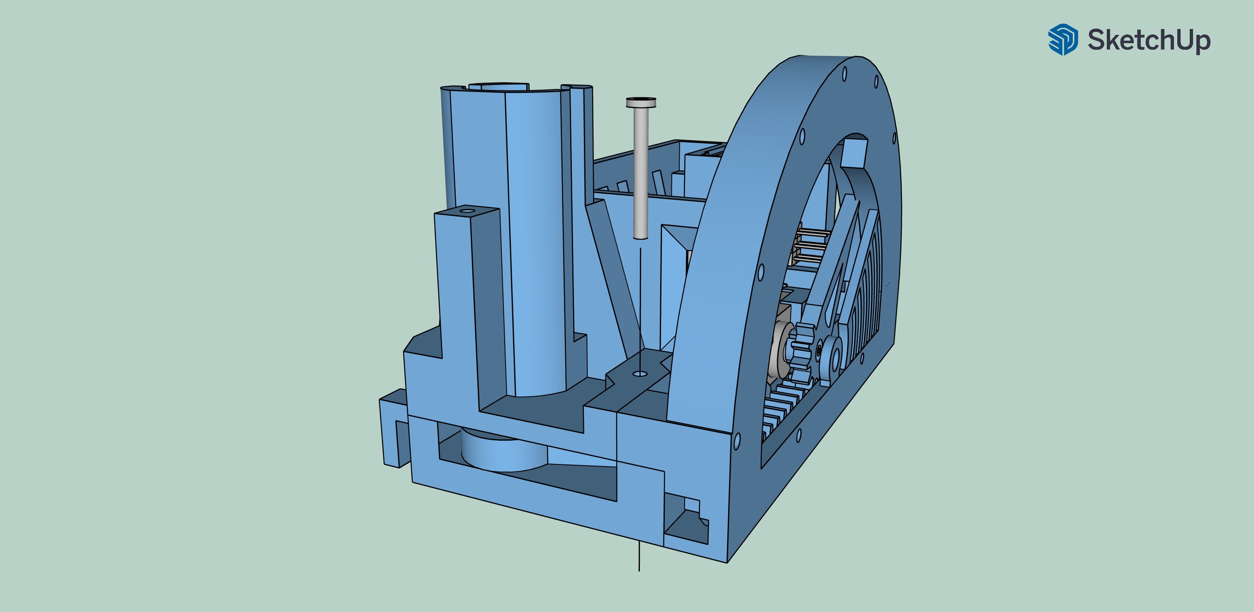
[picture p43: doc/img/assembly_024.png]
Secure Gauge Tower


Slide the `gauge_popup.stl` into the `gauge_tower.stl`.

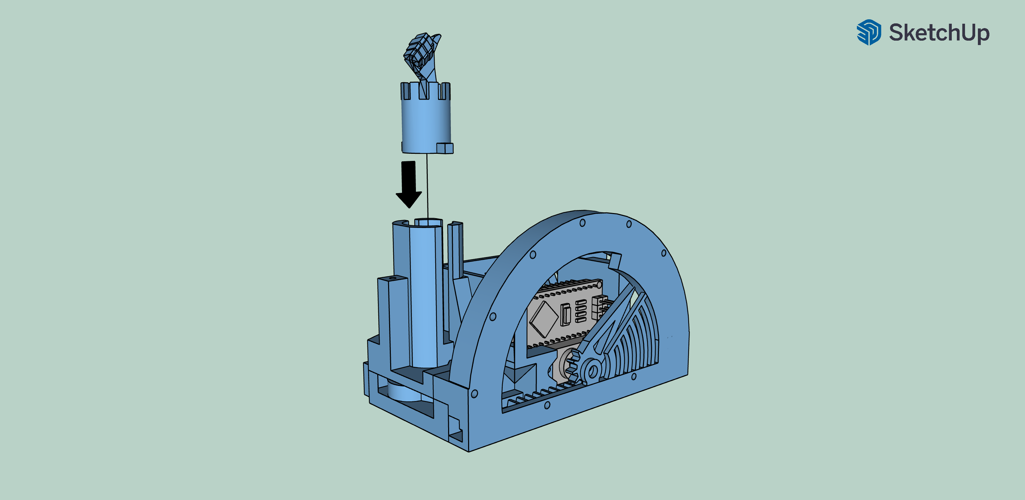
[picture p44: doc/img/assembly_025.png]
Slide Gauge Popup


Ensure the `gauge_popup.stl` is hidden inside the `gauge_tower.stl` and can move freely up and down.

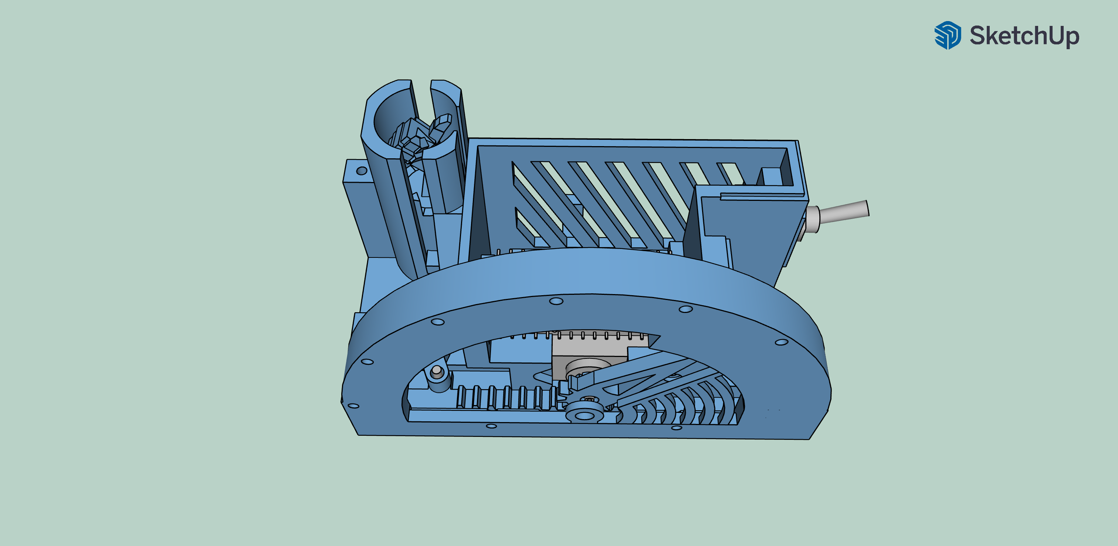
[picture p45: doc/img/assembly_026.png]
Gauge Popup Hidden


### Install Top Cover

Slide the `gauge_gear_large.stl` into the slot of the `gauge_case.stl`. This step will not secure the gear yet; we’ll take care of that in the next steps.

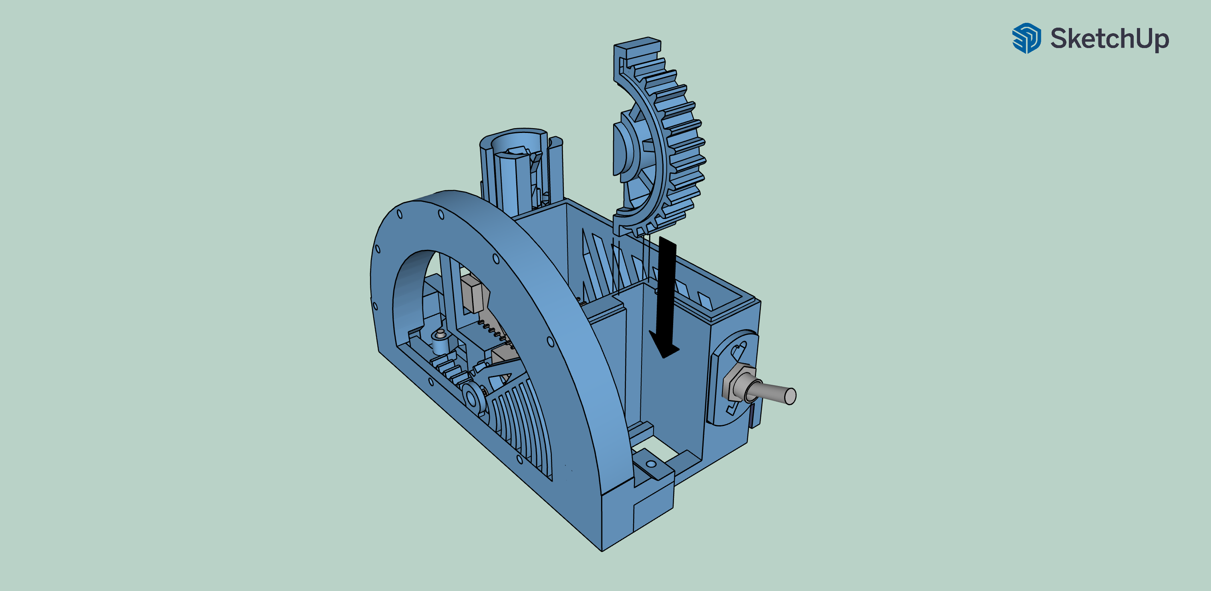
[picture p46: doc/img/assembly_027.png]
Slide Gauge Gear Large


Place the previously assembled top cover onto the housing (`gauge_case.stl`), ensuring it secures the `gauge_gear_large.stl` and aligns with `gauge_tower.stl`.

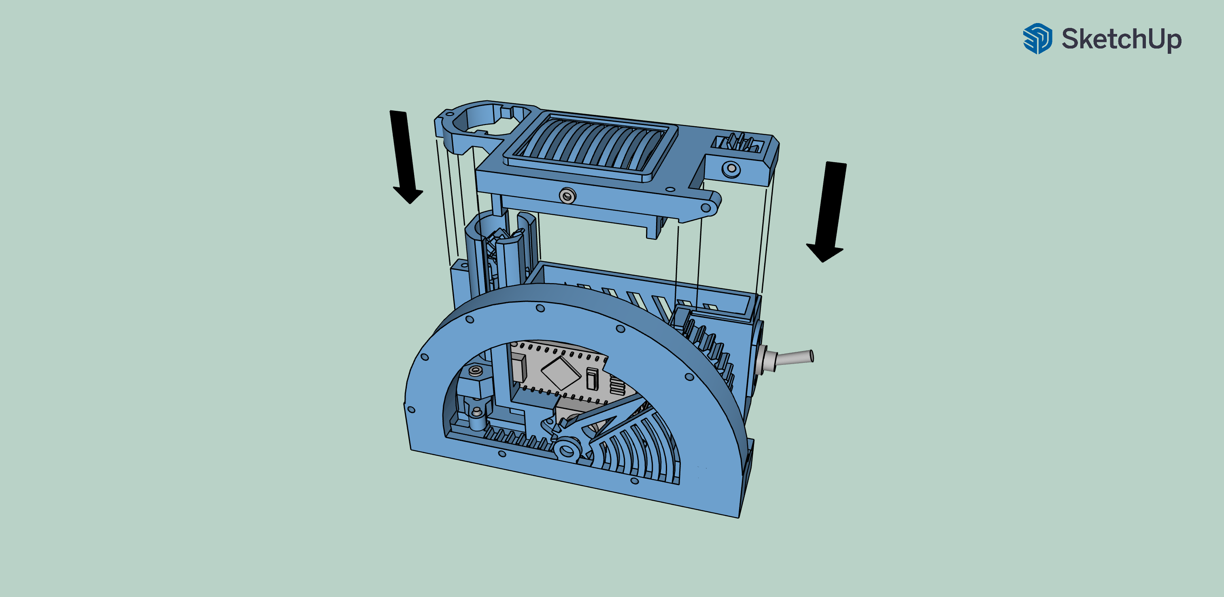
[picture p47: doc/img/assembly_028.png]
Place Top Cover


Secure the top cover with an M2x16 screw to hold everything firmly in place.

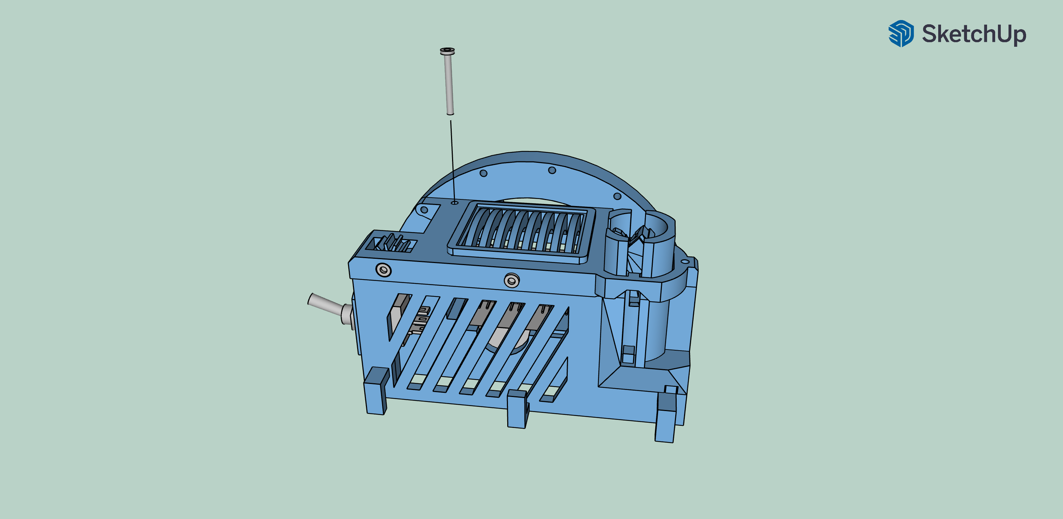
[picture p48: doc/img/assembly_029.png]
Secure Top Cover


Slide the `gauge_tower_top.stl` into the `gauge_tower.stl`, ensuring a snug fit. Secure it with an M2x16 screw.

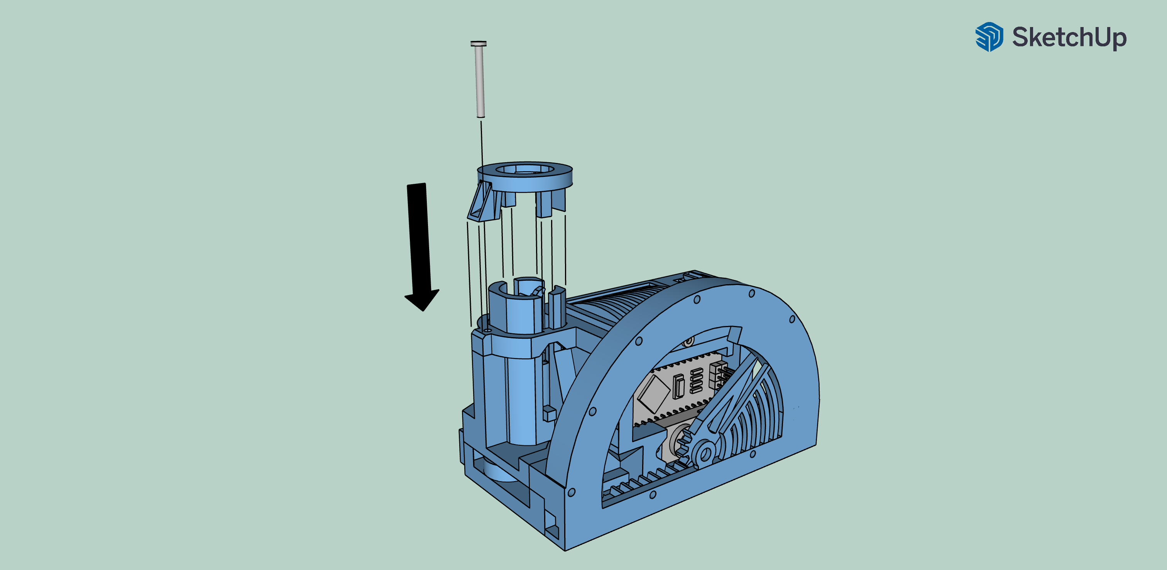
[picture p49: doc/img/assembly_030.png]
Slide Gauge Tower Top


Secure the scale with an M2x8 screw.

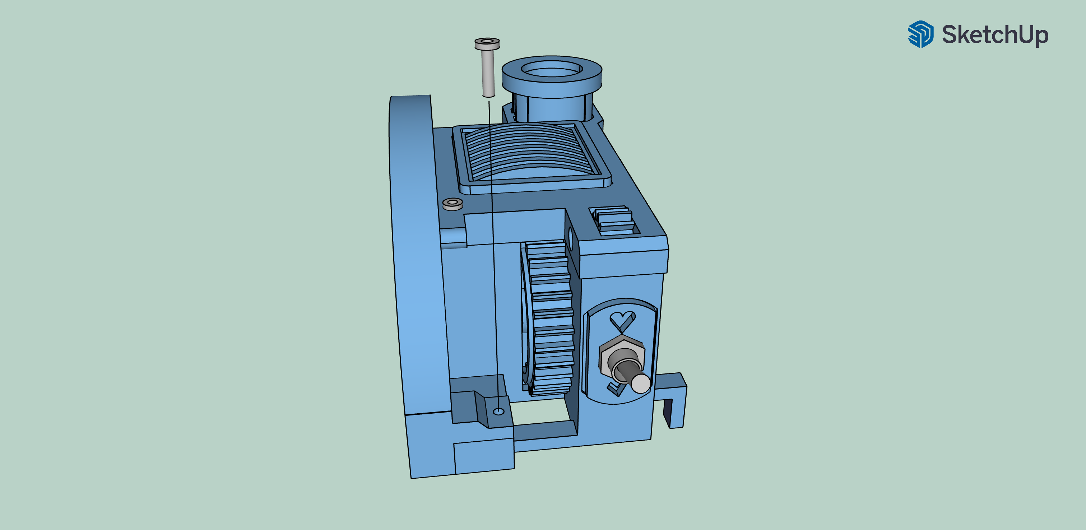
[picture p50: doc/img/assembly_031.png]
Secure Scale


### Install Scale Decors

Mount the `gauge_scale_ticks.stl` onto the casing (`gauge_case.stl`) by securing it with five M2x8 screws. Note that the last, most right screw hole should be left empty for now.

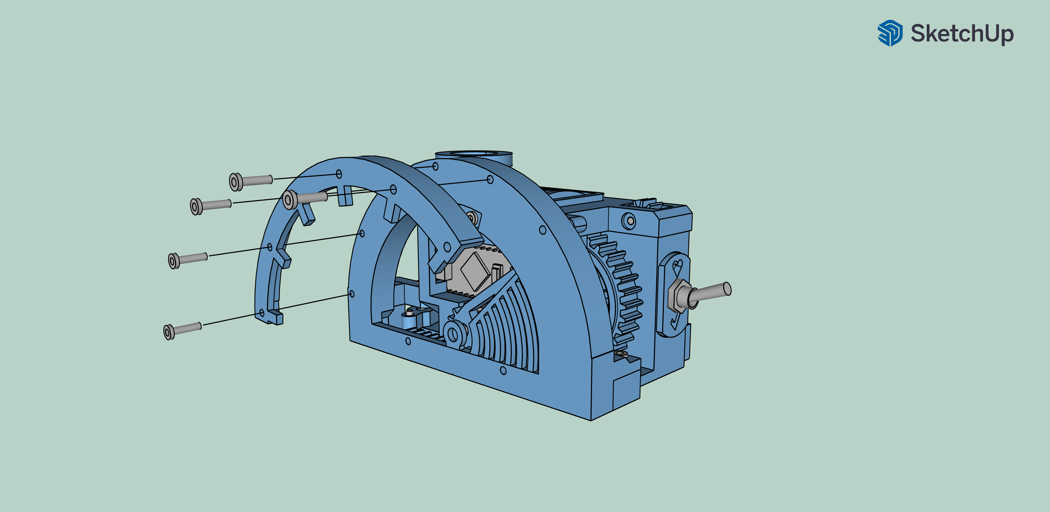
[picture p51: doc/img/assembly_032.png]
Mount gauge_scale_ticks.stl


Once the `gauge_scale_ticks.stl` is in place, use an M2x16 screw to securely mount the scale into the housing (`gauge_case.stl`).

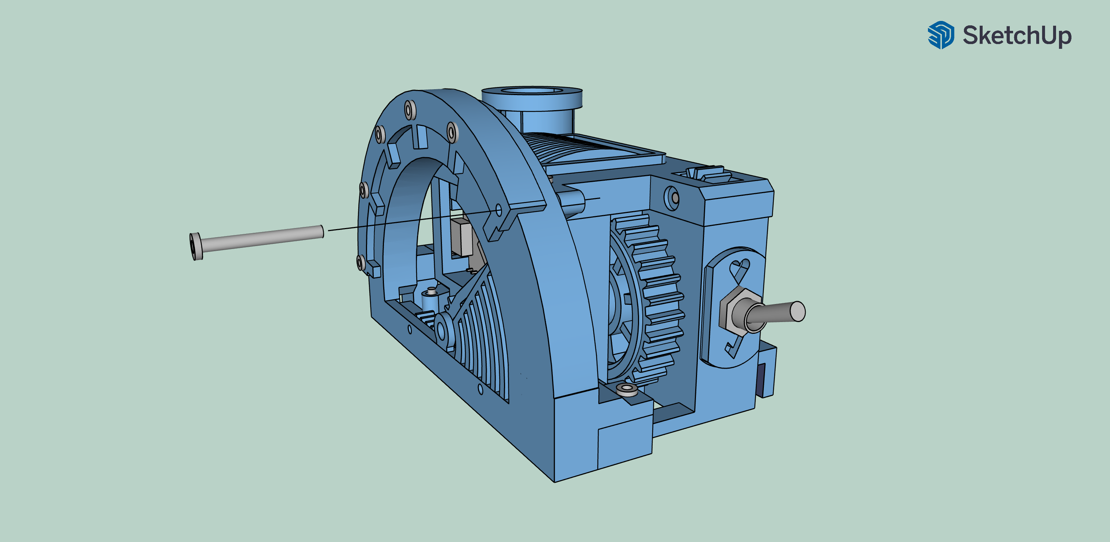
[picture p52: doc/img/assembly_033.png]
Mount Scale with M2x16 Screw


Finally, mount the `gauge_scale_front.stl` onto the device using two M2x8 screws.

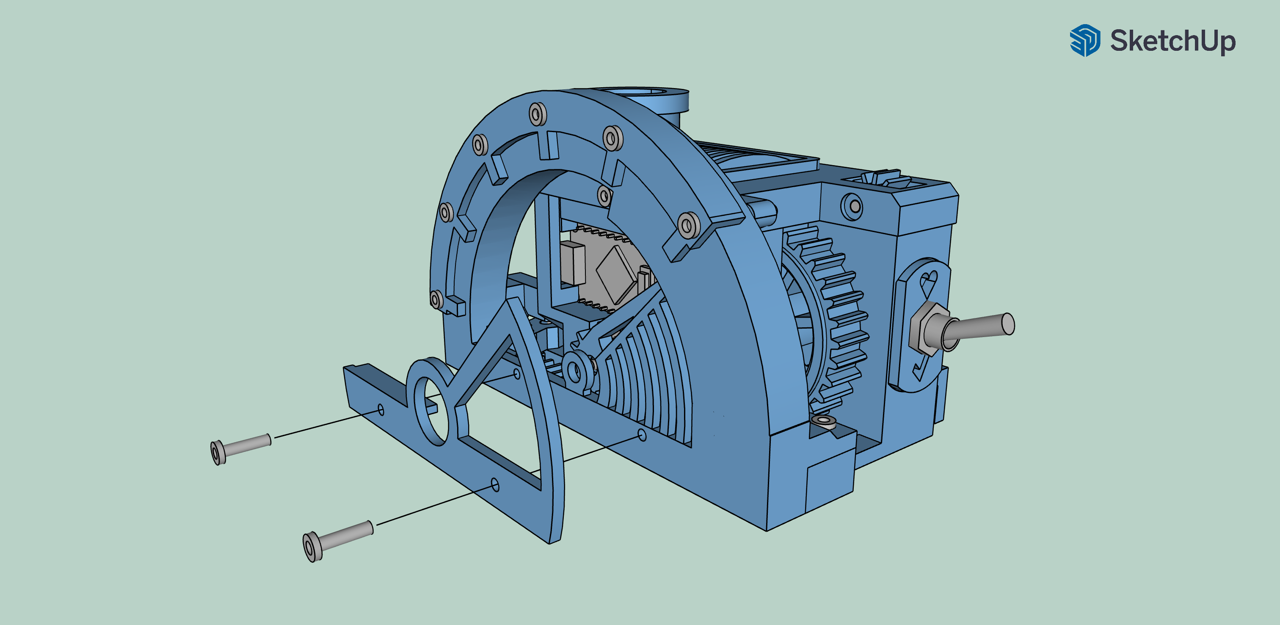
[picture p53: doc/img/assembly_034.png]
Mount gauge_scale_front.stl


This completes the installation of the scale decors for your Brass Thumb Pomodoro. Ensure all screws are securely fastened for stable and accurate operation of the device.

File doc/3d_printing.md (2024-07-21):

# 3D Printing

The Brass Thumb Pomodoro features 3D-printed components to embody its steampunk aesthetic. To achieve the optimal look, print the parts using PLA filament in two colors: matte black and brass. All model files are located in the `./model/stl` directory, and none of the prints require any support structures. Below are the specific files you need to print, along with their respective colors.

## List of Files to Print

| Preview | STL File | Color |
|---|---|---|
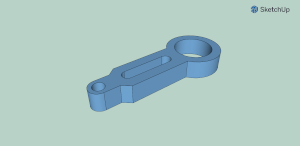
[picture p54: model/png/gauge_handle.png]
Gauge Handle
|  | [`gauge_handle.stl`](../model/stl/gauge_handle.stl) | Matte Black  |
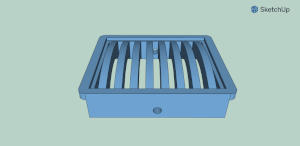
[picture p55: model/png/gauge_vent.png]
Gauge Vent
|  | [`gauge_vent.stl`](../model/stl/gauge_vent.stl) | Matte Black  |
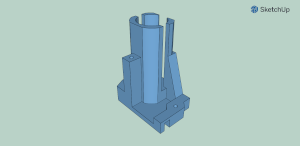
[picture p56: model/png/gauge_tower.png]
Gauge Tower
|  | [`gauge_tower.stl`](../model/stl/gauge_tower.stl) | Matte Black  |
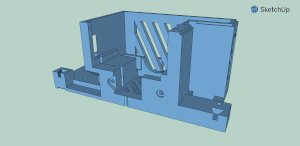
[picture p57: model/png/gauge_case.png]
Gauge Case
|  | [`gauge_case.stl`](../model/stl/gauge_case.stl) | Matte Black  |
| Gauge Popup | [`gauge_popup.stl`](../model/stl/gauge_popup.stl) | Brass |
| Gauge Cap | [`gauge_cap.stl`](../model/stl/gauge_cap.stl) | Brass |
| Gauge Slider | [`gauge_slider.stl`](../model/stl/gauge_slider.stl) | Matte Black  |
| Gauge Gear Small  | [`gauge_gear_small.stl`](../model/stl/gauge_gear_small.stl) | Matte Black  |
| Gauge Scale Ticks| [`gauge_scale_ticks.stl`](../model/stl/gauge_scale_ticks.stl) | Brass |
| Gauge Tag | [`gauge_tag.stl`](../model/stl/gauge_tag.stl) | Brass |
| Gauge Gear Large  | [`gauge_gear_large.stl`](../model/stl/gauge_gear_large.stl) | Brass |
| Gauge Scale Front| [`gauge_scale_front.stl`](../model/stl/gauge_scale_front.stl) | Brass |
| Gauge Scale Body  | [`gauge_scale_body.stl`](../model/stl/gauge_scale_body.stl) | Matte Black  |
| Gauge Pointer | [`gauge_pointer.stl`](../model/stl/gauge_pointer.stl) | Brass |
| Gauge Tower Top | [`gauge_tower_top.stl`](../model/stl/gauge_tower_top.stl) | Matte Black  |

## Additional Printing Information

1. **Print Settings**: Ensure you're using the right settings for PLA on your 3D printer, such as the correct temperature for both the nozzle and bed. The typical settings include a nozzle temperature of 200-210°C and a bed temperature of 50-60°C.

2. **Quality and Layer Height**: For the best appearance and mechanical performance, a layer height of 0.2mm is generally recommended. However, for finer details, you may opt for a smaller layer height around 0.1mm.

3. **Infill**: An infill density around 20% is usually sufficient for these parts.

4. **Assembly Guidelines**: Once all parts are printed, carefully remove them from the print bed. Use sandpaper or a file to smooth out any rough edges or imperfections, especially on moving parts such as the gears and the slider.

5. **Fit and Finish**: Make sure all parts fit together snugly before final assembly. You may need to test-fit parts and make minor adjustments to ensure a perfect assembly. This is particularly important for moving parts and mechanical connections.

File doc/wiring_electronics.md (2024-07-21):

# Wiring Electronics

To assemble the wiring for the **Brass Thumb Pomodoro**, follow the diagram provided below. 

Here's a detailed step-by-step guide:

1. **Servo Motor Connections**:
   - Connect the signal pin of the servo motor (usually the yellow or white wire) to pin `D9` on the Arduino Nano.
   - Use female jumper wires to connect the `VCC` (red wire) and `GND` (black wire) of the servo motor to the respective `5V` and `GND` pins on the Arduino Nano. 
   - If the servo motor's pins are merged together in a single socket, you may need to modify the connections to fit the Arduino pins that are not adjacent to each other.

2. **Switch Connections**:
   - Solder female jumper wire to the one side of the switch and connect it to pin `D2` on the Arduino Nano.
   - Solder female jumper wire to the middle pin of the switch and connect it to the `GND` pin on the Arduino Nano.
   - Solder female jumper wire to the other side of the switch and connect it to pin `D3` on the Arduino Nano.

Brass Thumb Pomodoro Wiring

## Additional Wiring Information

1. **Connector Types and Usage**: For this project, using female jumper wires is recommended for connecting components to the Arduino Nano.

2. **Soldering Tips**: When soldering wires to the switch, ensure that your soldering iron is at the right temperature (around 350°C). Tin the wire and the switch terminal before joining them together. Apply heat to the joint and feed solder into the connection. Always work in a well-ventilated area and wear safety goggles.

3. **Power Supply Considerations**: The Arduino Nano and servo motor can be powered via the USB connection. Ensure your USB power source provides at least `500mA` of current. If using an external power source, verify that it meets the voltage and current requirements of your components.

4. **Cable Management**: Choosing the proper length of cables is crucial for both fitting the components inside the case and ensuring ease of assembly. Cables should be long enough to allow for easy connection and movement of components during assembly, but not so long that they create unnecessary bulk or clutter inside the case.

5. **Testing Connections**: Before powering on the device, test the continuity of your connections with a multimeter. Check for any shorts or open circuits. If the device does not function correctly, verify all connections against the wiring diagram and ensure that the Arduino Nano is properly programmed and connected.

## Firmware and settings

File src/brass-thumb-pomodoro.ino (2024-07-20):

#include <Servo.h>
#include "libs/ModeSwitch.h"
#include "libs/Blink.h"
#include "libs/Clock.h"
#include "config.h"

// Constant for step time delay
constexpr float STEP_TIME = 30;

Servo gaugeServo;        
ModeSwitch modeSwitch;            
Blink blink;             
Clock clock = Clock(WORK_TIME, BREAK_TIME);

float pos = MAX_POS; 

/**
 * Welcome sequence to initialize the servo with a predefined movement.
 */
void welcome() {
  gaugeServo.write(MAX_POS);
  delay(1000);
  gaugeServo.write(POP_POS);
  delay(2000);
  gaugeServo.write(pos);
  delay(1000);
}

/**
 * Arduino setup function, runs once at the start.
 */
void setup() {
  Serial.begin(9600);
  blink.attach(LED_BUILTIN);

  gaugeServo.attach(SERVO_PIN);

  modeSwitch.attach(WORK_PIN, BREAK_PIN);
  modeSwitch.onStartWork(restartClock);
  modeSwitch.onResumeWork(startClock);
  modeSwitch.onStartBreak(restartClock);
  modeSwitch.onResumeBreak(startClock);
  modeSwitch.onStartIdle(stopClock);

  welcome();

  Serial.println("=== CLOCK READY ===");
  blink.setPeriod(0);
}

/**
 * Callback function to restart the clock.
 */
void restartClock(int mode) { clock.restart(mode); }

/**
 * Callback function to start the clock.
 */
void startClock(int mode) { clock.start(mode); }

/**
 * Callback function to stop the clock.
 */
void stopClock() { clock.stop(); }

/**
 * Function to update the clock based on the current mode and time.
 */
void runClock() {
  modeSwitch.update();  // Update the mode switch state
  int mode = modeSwitch.getMode();
  float progress = clock.getProgress();

  pos = MIN_POS + (progress) * (MAX_POS - MIN_POS);

  if(clock.isComplete()) {
    blink.setPeriod(1);
  } else if(clock.isRunning()) {
    blink.setPeriod(1, 1000/STEP_TIME-1);
  } else {
    blink.setPeriod(0);
  }

  if(pos <= MIN_POS && mode == WORK_MODE) {
    pos = POP_POS;
  }

  gaugeServo.write(constrain(pos, 0, 180)); // Write constrained position to servo
}

/**
 * Arduino main loop function, runs repeatedly.
 */
void loop() {
  runClock();
  blink.step();
  delay(STEP_TIME);
}

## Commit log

2024-07-20 add models
    [gauge_cap.skp, gauge_cap.stl, gauge_case.skp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]
2024-07-20 improve 3d print instructions
2024-07-20 add wiring instructions
    [wiring.fzz]
2024-07-20 improve wiring docs
2024-07-21 initialize assembly docs
2024-07-21 complete assembly prep
2024-07-21 add main assembly steps
2024-07-22 add materials list
